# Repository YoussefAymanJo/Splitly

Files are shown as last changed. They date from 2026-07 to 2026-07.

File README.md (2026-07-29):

## Splitly

## Description

corne  hybrid wireless keyboard based .As it consists of a left part keyboard  connected to pc wired ,and right part keyboard powered by a rechargeable Battery which can operate up to week and connected to left part via bluetooth.And operated by nice Nano and CAT display. And a  numpad with RGB colours, connected wired to pc and powered by pico rp2040 .
## Why it was built
I built this,beacause i always need full split mechanical keyboard,but i need to customize it features by myself.So this keyboard it custosmized to my needings.Also,it has customized features based on usage.Splitly is not just regular keybaord but,desgined to be my companion.
## How to use it / Build it
Firsly,printing all 3d models after that fabricate PCB.After that assemble mx switches,MCU and battery management of pcb.then assemble all this parts together.finally,upload firmware on nice nano and pico,the test all 
## Schematic
I made the schematic and keyboard matrix for the corne keyboard, then the  numpad  .

### Left Part



### Right Part



### Numpad



## PCB
I routed the pcb ,then i outlined the shape of 2 keboard parts and numpad .

### Left Part



### Right Part


### Numpad


## CAD
I started   sketching the plate for left & right part keyboard,the i the Enclosure , then the top cover.After that i worked on numpad  plate, then enclosure and top cover,finally i redered them all.

### Left Part





### Right Part






### Numpad






## Firmware
I used kmk with CircuitPython as firmware,and made code for the left  & right part which is keyboard and the numpad

### Left Part






### Right Part





### Numpad


## BOM 
I made the BOM  and needed materials ,in egypt then convert its price to USD dollar.


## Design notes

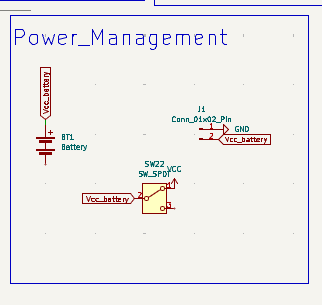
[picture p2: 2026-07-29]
images/Screenshot 2026-07-29 151413.png

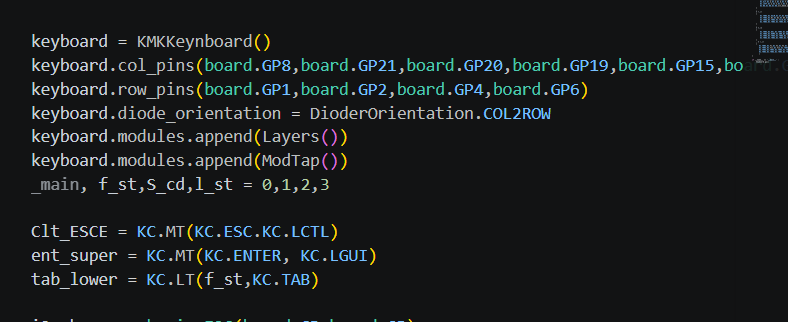
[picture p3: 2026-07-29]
images/Screenshot 2026-07-29 154053.png

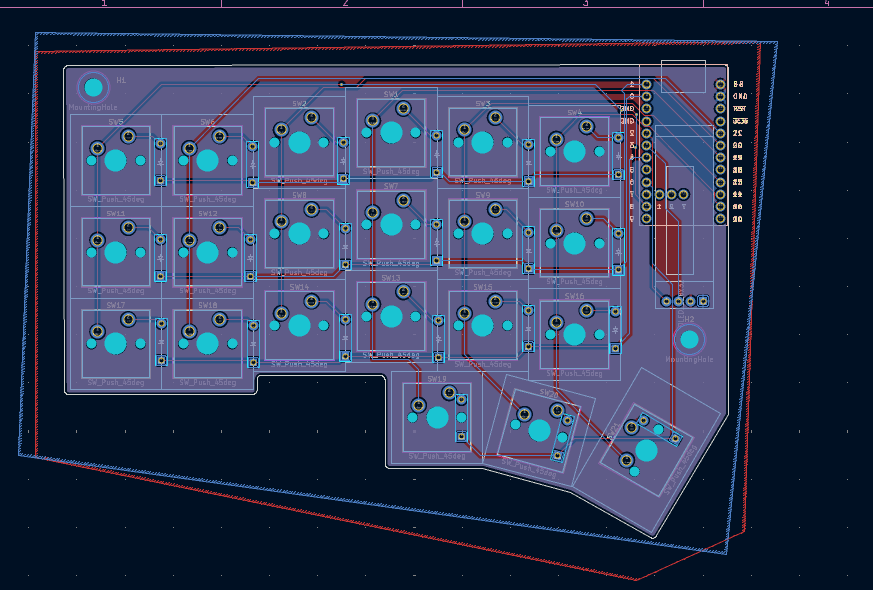
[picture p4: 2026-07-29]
images/Screenshot 2026-07-29 140454.png

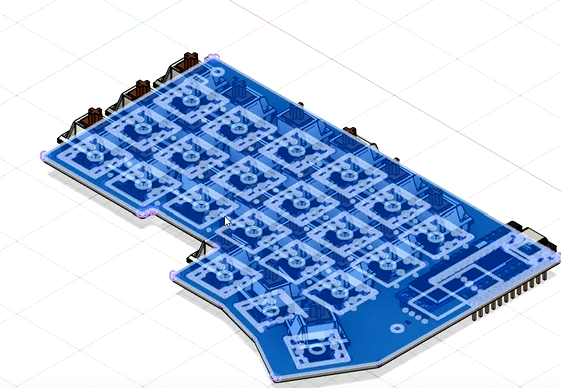
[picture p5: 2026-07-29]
images/Screenshot 2026-07-29 143937.png

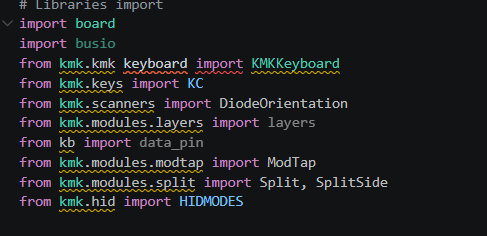
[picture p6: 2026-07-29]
images/Screenshot 2026-07-29 154227.png

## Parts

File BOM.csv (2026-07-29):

Item | descritption | QT | Price | link
Main keyboard_pcb | fabricate and printing it | 3 | 32 | none
3d printing | Printing keyboard parts | 9 | 16 | None
Nice_Nano | Mcu for main keyboard | 2 | 20 | https://www.amazon.com/NRF52840-Development-Bluetooth-Charging-Management/dp/B0DH9FP3JP
Pico | MCU for NUMPAD | 1 | 11.46 | https://microohm-eg.com/raspberry-pi-pico/
Oled Display | Display animation in keyboard | 1 | 3.16 | https://www.ram-e-shop.com/ar/shop/oled-0-96-4pin-oled-0-96-4pin-lcd-display-module-i2c-iic-communicate-7772
Oled display 128*32 | Display animation in keyboard | 1 | 4.27 | https://uge-one.com/product/color-graphic-0-91-i2c-oled-128x32-blue-display-module-ssd1306/
Mx_switches | For keyboard and numpad keys | 108 | 11.19 | https://www.temu.com/ul/kuiper/un9.html?subj=goods-un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
Dsa keycaps | For keyboard and numpad keys | 100 | 19.68 | https://www.aliexpress.us/item/3256808417233251.html?curPageLogUid=AyCtfngZUzYL
M3 shcs 12 mm srews | For connecting enclosures parts together | 20 | 2.31 | https://www.amazon.eg/-/en/Screws-City-12mm-Allen-Socket/dp/B08GY9YFYC?adgrpid=126096347022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
M3 shcs 5 mm screwss | for pcb connection with enclosure | 20 | 1.82 | https://www.temu.com/ul/kuiper/un9.html?subj=goods-un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
Heat insert | Connect srews with enclosure | 20 | 1.92 | https://www.temu.com/ul/kuiper/un9.html?subj=goods-un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
Total | None | None | 123.81

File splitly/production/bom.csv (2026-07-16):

Designator | Footprint | Quantity | Value | LCSC Part #
D1, D10, D11, D12, D13, D14, D15, D16, D17, D18, D19, D2, D20, D21, D3, D4, D5, D6, D7, D8, D9 | Diode_DO-35 | 21 | ~
J1 | OLED_128x32 | 1 | OLED_128x32
SW1, SW10, SW11, SW12, SW13, SW14, SW15, SW16, SW17, SW18, SW19, SW2, SW20, SW3, SW4, SW5, SW6, SW7, SW8, SW9 | MX_PCB_1.00u | 20 | SW_Push_45deg
SW21 | MX_PCB_1.50u | 1 | SW_Push_45deg
U1 | Nice_Nano_V2 | 1 | Nice_Nano_V2

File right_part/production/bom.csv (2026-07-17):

Designator | Footprint | Quantity | Value | LCSC Part #
D1, D10, D11, D12, D13, D14, D15, D16, D17, D18, D19, D2, D20, D21, D3, D4, D5, D6, D7, D8, D9 | Diode_DO-35 | 21 | ~
J1 | JST_PH_S2B-PH-K_1x02_P2.00mm_Horizontal | 1 | Conn_01x02_Pin
SW1 | MX_PCB_1.00u | 1 | I
SW10 | MX_PCB_1.00u | 1 | H
SW11 | MX_PCB_1.00u | 1 | ;
SW12 | MX_PCB_1.00u | 1 | Alt
SW13 | MX_PCB_1.00u | 1 | ,
SW14 | MX_PCB_1.00u | 1 | M
SW15 | MX_PCB_1.00u | 1 | .
SW16 | MX_PCB_1.00u | 1 | N
SW17 | MX_PCB_1.00u | 1 | /
SW18 | MX_PCB_1.00u | 1 | Func
SW19 | MX_PCB_1.00u | 1 | shift
SW2 | MX_PCB_1.00u | 1 | U
SW20 | MX_PCB_1.50u | 1 | bksp
SW21 | MX_PCB_1.00u | 1 | Space
SW22 | SW_Slide_SPDT_Angled_CK_OS102011MA1Q | 1 | SW_SPDT
SW3 | MX_PCB_1.00u | 1 | O
SW4 | MX_PCB_1.00u | 1 | Y
SW5 | MX_PCB_1.00u | 1 | P
SW6 | MX_PCB_1.00u | 1 | Del
SW7 | MX_PCB_1.00u | 1 | K
SW8 | MX_PCB_1.00u | 1 | J
SW9 | MX_PCB_1.00u | 1 | L
U1 | Nice_Nano_V2 | 1 | Nice_Nano_V2

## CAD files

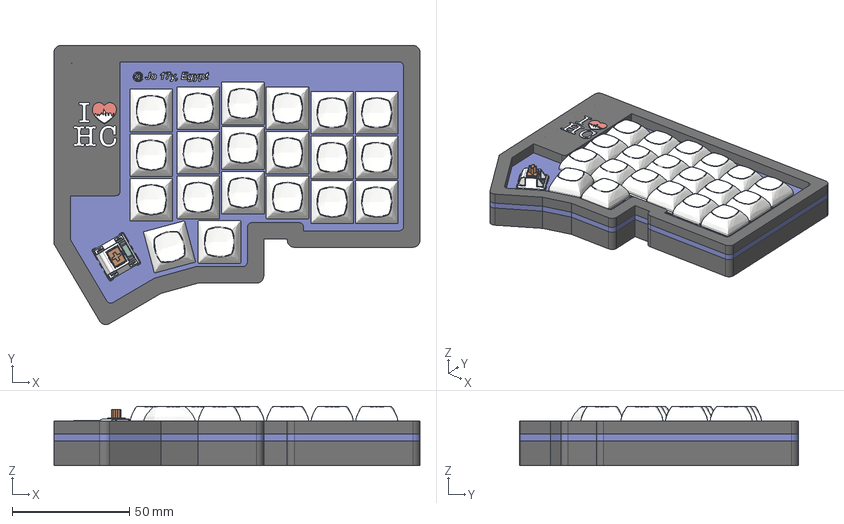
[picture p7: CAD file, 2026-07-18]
Production/Right_Assembly.step
155.9 x 119.0 x 25.3 mm
MX_PCB x 21
JST_PH_S2B-PH-K_1x02_P2.00mm_Horizontal
PinHeader_1x12_P2.54mm_Vertical.step
User Library-TYPE-C-31-M-14.step
MICRO_603 resistor 102
micro_crystal 5x3
MICRO_led
micro_MIC5219
SW_Slide_SPDT_Angled_CK_OS102011MA1Q
Diode_DO-35 x 21
right_part_copper
right_part_via
right_part_silkscreen
right_part_silkscreen_1
right_part_soldermask
right_part_soldermask_1
right_part_PCB

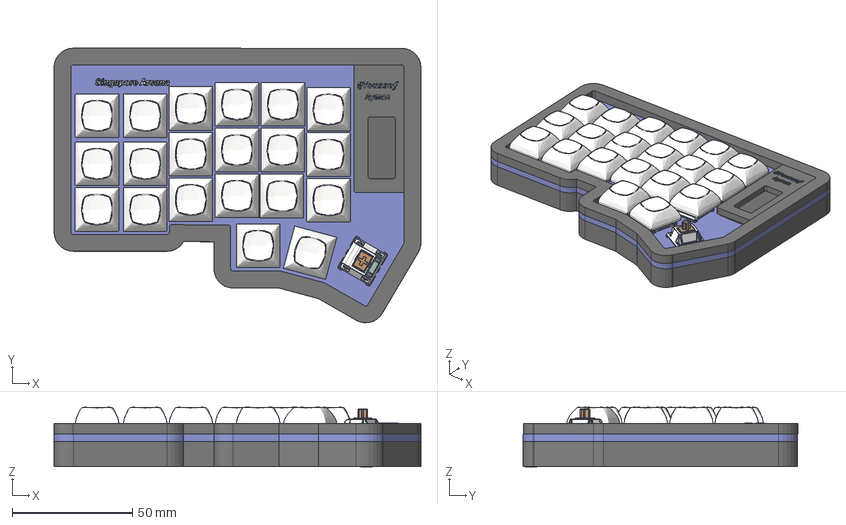
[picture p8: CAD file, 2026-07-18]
Production/Left_Assembly.step
152.7 x 114.3 x 24.8 mm

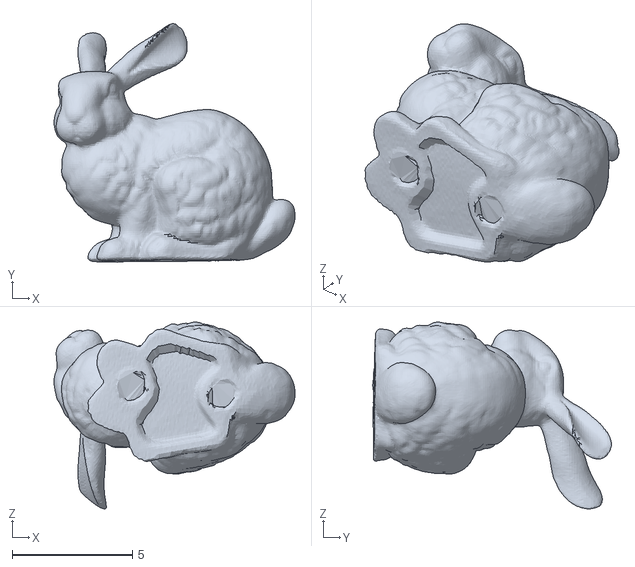
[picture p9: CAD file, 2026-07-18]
Firmware/adafruit-circuitpython-bundle-10.x-mpy-20260606/examples/bno055/bno055_webgl_demo/static/bunny.obj
10.0 x 9.94 x 7.77

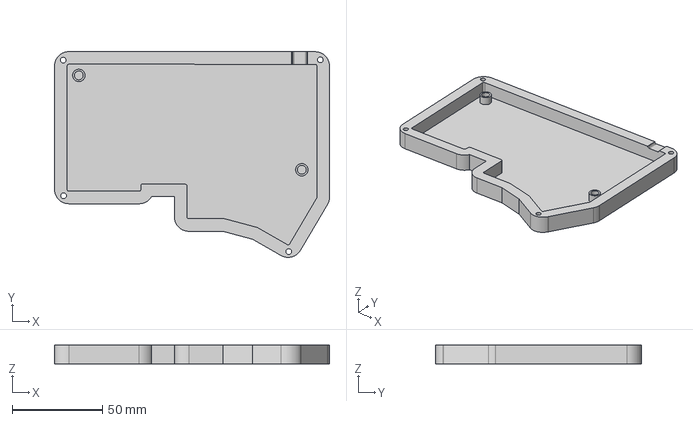
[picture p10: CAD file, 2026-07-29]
Production/Left_ENclosure.step
152.7 x 114.3 x 10.5 mm

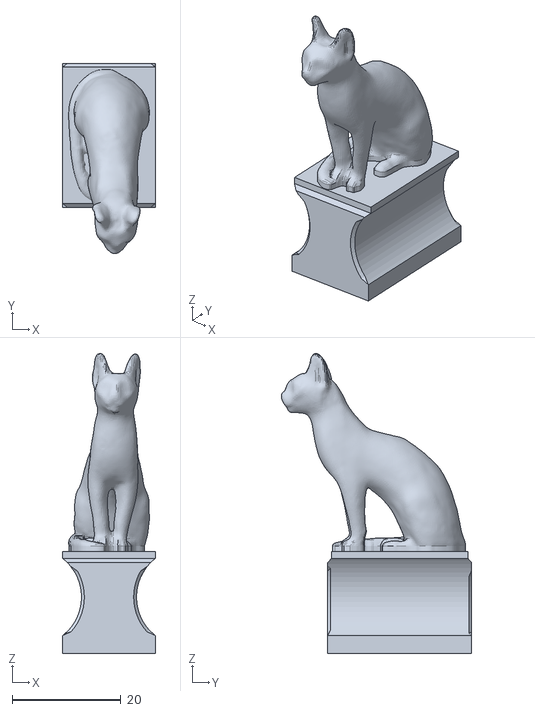
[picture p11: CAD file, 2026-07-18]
Firmware/adafruit-circuitpython-bundle-10.x-mpy-20260606/examples/bno055/bno055_webgl_demo/static/cat_top.stl
17.0 x 34.9 x 55.1

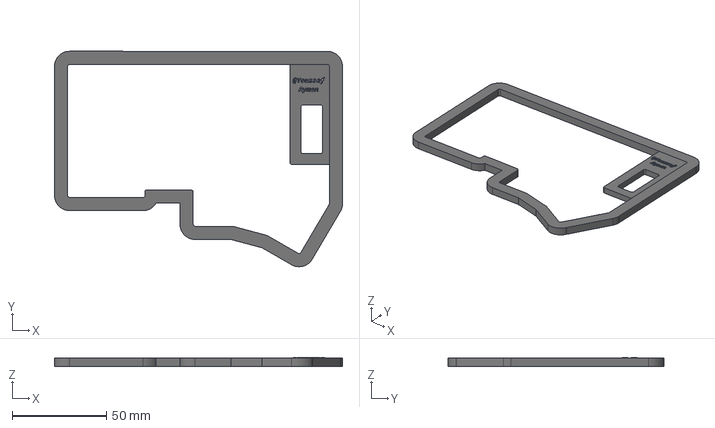
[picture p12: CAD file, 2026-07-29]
Production/left_top_cover.step
152.7 x 114.3 x 4.70 mm

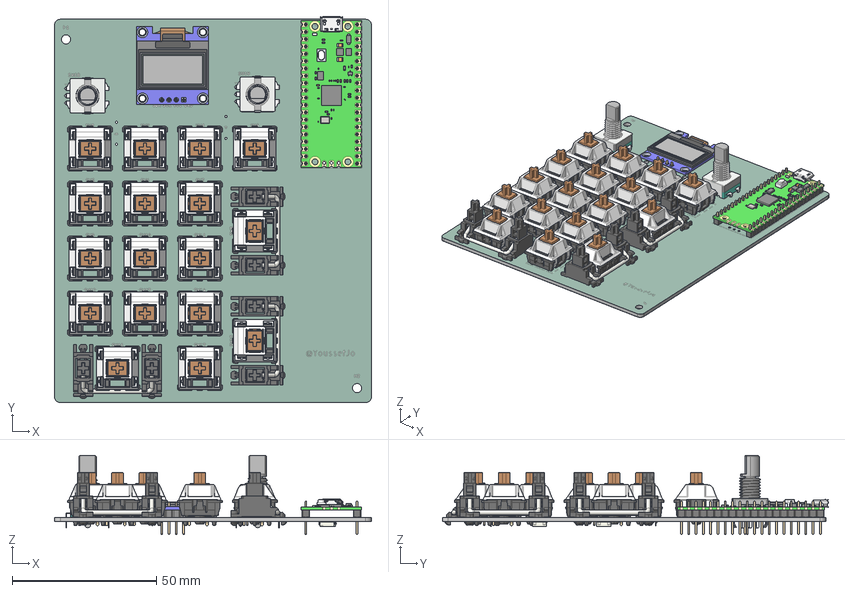
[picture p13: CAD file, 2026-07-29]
Production/pad.step
110.0 x 134.0 x 27.5 mm
MX_PCB x 17
Stabilizer_MX_2.00u x 3
OLED
EC11 x 2
PinHeader_1x20_P2.54mm_Vertical.step
SMD Resistor, Configurable, Raspberry Pi Pico-R3_R7
U2, RT6150B-33GQW, Buck Boost Converter, Raspberry Pi Pico-R3
SMD Capacitor, Configurable, Raspberry Pi Pico-R3_C3
SMD Resistor, Configurable, Raspberry Pi Pico-R3_R14
SMD Capacitor, Configurable, Raspberry Pi Pico-R3_C12
SMD Resistor, Configurable, Raspberry Pi Pico-R3_R2
SMD Capacitor, Configurable, Raspberry Pi Pico-R3_C13
SMD Resistor, Configurable, Raspberry Pi Pico-R3_R12
U3, W25Q16JVUXIQ, Serial NOR Flash 16 Mbit, Raspberry Pi Pico-R3
SMD Resistor, Configurable, Raspberry Pi Pico-R3_R5
SMD Resistor, Configurable, Raspberry Pi Pico-R3_R1
MicroUSB Port, Raspberry Pi Pico-R3
X1, X12M000000S096, 12 Mhz Crystal Resonator, Raspberry Pi Pico-R3
SMD Capacitor, Configurable, Raspberry Pi Pico-R3_C2
SMD Resistor, Configurable, Raspberry Pi Pico-R3_R4
Q1, MOSFET, DMG1012T, Raspberry Pi Pico-R3
SMD Capacitor, Configurable, Raspberry Pi Pico-R3_C11
SMD Resistor, Configurable, Raspberry Pi Pico-R3_R6
RP2040 Microcontroller, Raspberry Pi Pico-R3
SMD Resistor, Configurable, Raspberry Pi Pico-R3_R9
D1, Diode, Schottky, Raspberry Pi Pico-R3
SMD Resistor, Configurable, Raspberry Pi Pico-R3_R3
SMD Capacitor, Configurable, Raspberry Pi Pico-R3_C8
SMD Capacitor, Configurable, Raspberry Pi Pico-R3_C6
SMD Capacitor, Configurable, Raspberry Pi Pico-R3_C17
SMD Capacitor, Configurable, Raspberry Pi Pico-R3_C16
SMD Capacitor, Configurable, Raspberry Pi Pico-R3_C7
SMD Resistor, Configurable, Raspberry Pi Pico-R3_R11
SMD Capacitor, Configurable, Raspberry Pi Pico-R3_C4
D2, QSME-C194, LED, Raspberry Pi Pico-R3
SMD Capacitor, Configurable, Raspberry Pi Pico-R3_C14
SMD Resistor, Configurable, Raspberry Pi Pico-R3_R8
SW1, Tact Switch, Raspberry Pi Pico-R3
SMD Capacitor, Configurable, Raspberry Pi Pico-R3_C9
SMD Resistor, Configurable, Raspberry Pi Pico-R3_R15
SMD Capacitor, Configurable, Raspberry Pi Pico-R3_C5
SMD Resistor, Configurable, Raspberry Pi Pico-R3_R13
SMD Resistor, Configurable, Raspberry Pi Pico-R3_R10
SMD Capacitor, Configurable, Raspberry Pi Pico-R3_C10
L1, Inductor, Raspberry Pi Pico-R3
PCB, Raspberry Pi Pico-R3
SMD Capacitor, Configurable, Raspberry Pi Pico-R3_C1
SMD Capacitor, Configurable, Raspberry Pi Pico-R3_C15
SMD Capacitor, Configurable, Raspberry Pi Pico-R3_C18
LED_WS2812B_PLCC4_5.0x5.0mm_P3.2mm x 2
pad_silkscreen x 2
pad_soldermask x 2
pad_PCB

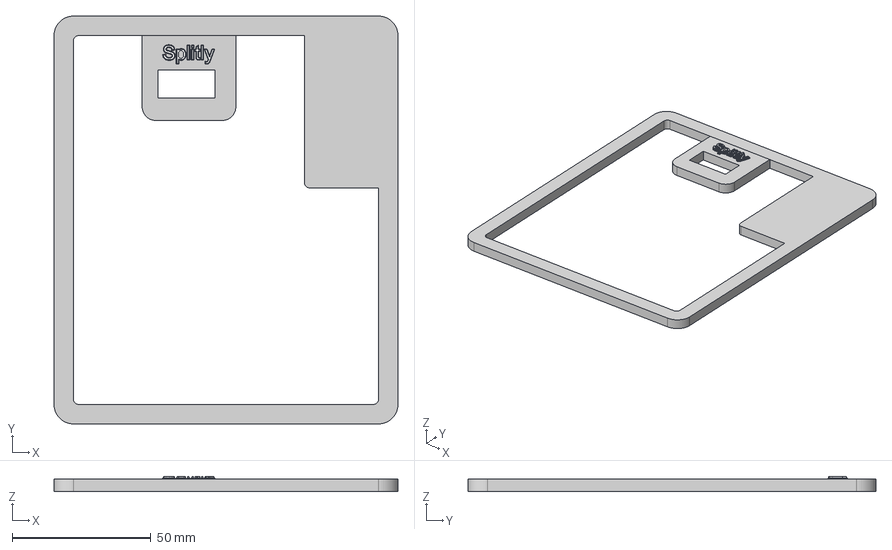
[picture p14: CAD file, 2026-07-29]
Production/Pad_top_cover.step
124.0 x 147.0 x 5.50 mm

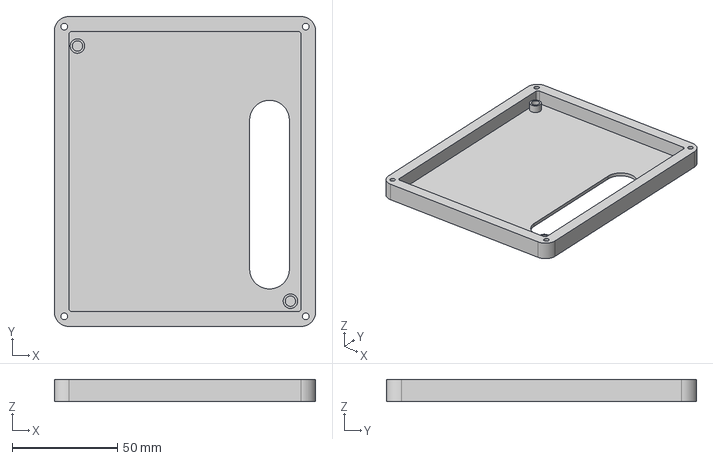
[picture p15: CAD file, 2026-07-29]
Production/Enclosure_pad.step
124.0 x 147.0 x 10.5 mm

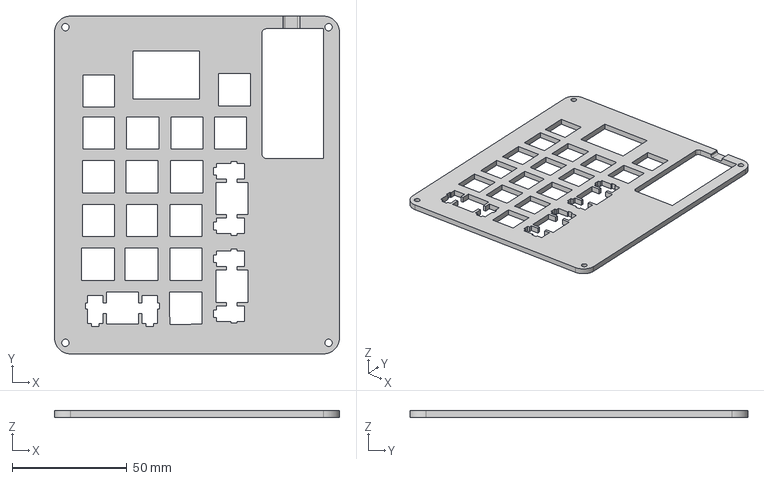
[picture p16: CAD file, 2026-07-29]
Production/Pad+plate.step
124.0 x 147.0 x 3.00 mm

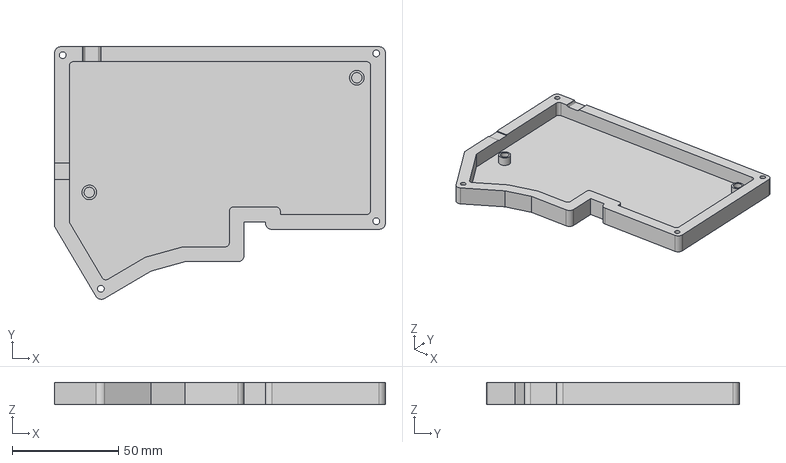
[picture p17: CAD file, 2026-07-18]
Production/Right_Enclosure.step
155.9 x 119.0 x 10.5 mm

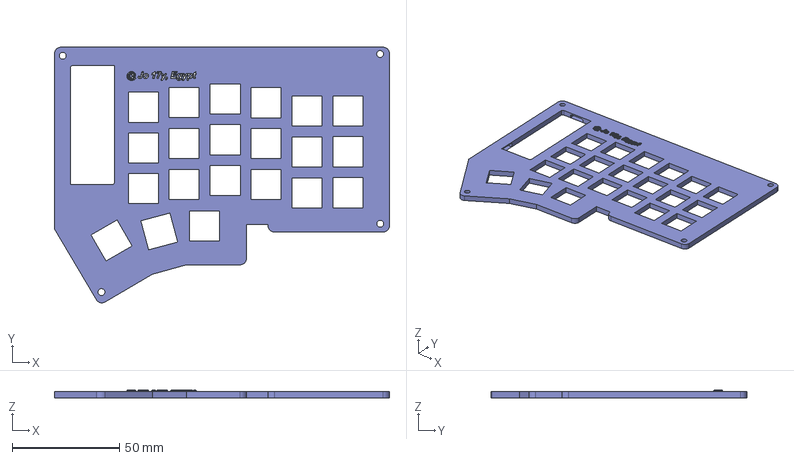
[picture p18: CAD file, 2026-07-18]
Production/Right_plate.step
155.9 x 119.0 x 3.50 mm

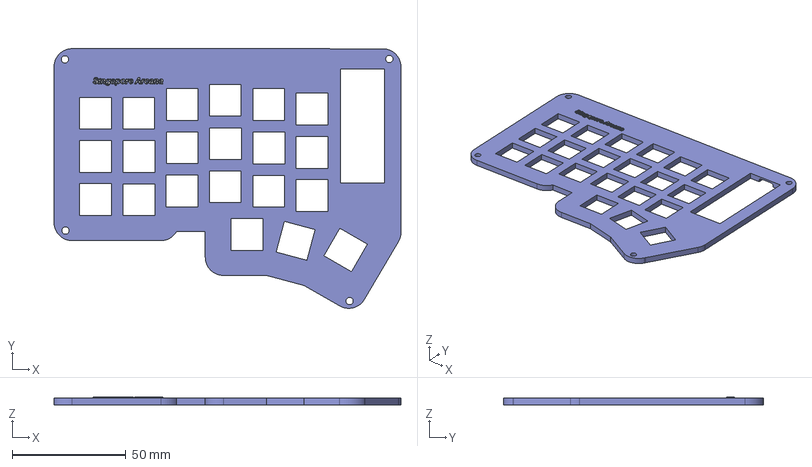
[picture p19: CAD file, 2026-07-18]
Production/Plate.step
152.7 x 114.3 x 3.50 mm

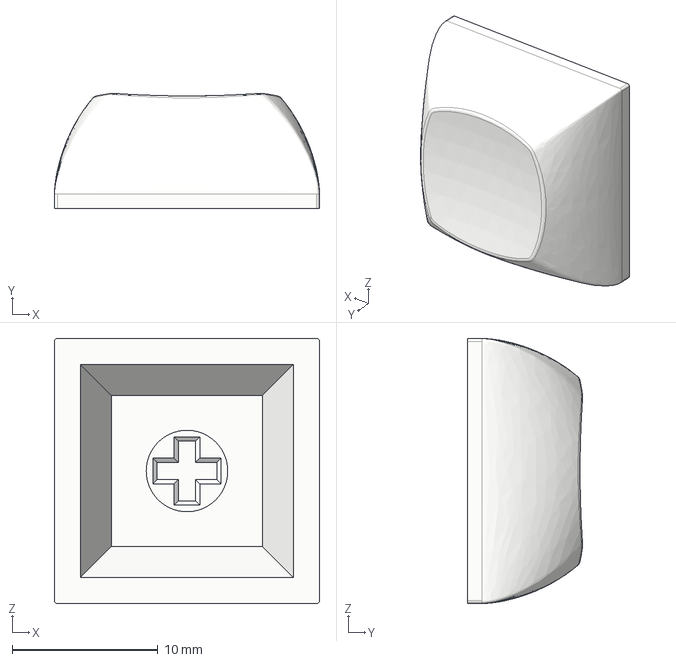
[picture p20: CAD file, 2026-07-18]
Production/DSA_.step
18.2 x 7.91 x 18.2 mm

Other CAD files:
Production/1.5u.step
Production/Right_top_cover.step
Production/M3 Threaded Insert_.step
Production/Battery.step
Production/M3x12 SHCS.step
Production/left_top_cover.f3d
Production/right_part.step
Production/splitly.step
Source_Files/Battery.f3d
Source_Files/Enclosure_pad.f3d
Source_Files/Left_Assembly.f3z
Source_Files/Left_ENclosure.f3d
Source_Files/Pad+plate.f3d
Source_Files/Pad_top_cover.f3d
Source_Files/Plate.f3d
Source_Files/RIght_plae.f3d
Source_Files/Right_Assembly.f3z
Source_Files/Right_Enclosure.f3d
Source_Files/Right_top_cover.f3d
Source_Files/leftPlate.f3d
efc796056b68a6326252bc44c872f28c73b40230_switch.dxf

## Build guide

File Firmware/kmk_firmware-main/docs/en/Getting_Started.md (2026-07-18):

# Getting Started
> Life was like a box of chocolates. You never know what you're gonna get.

KMK is a keyboard focused layer that sits on top of [CircuitPython](https://circuitpython.org/). As such, it should work with most [boards that support CircuitPython](https://circuitpython.org/downloads). KMK requires CircuitPython version 7.3 or above.
Known working and recommended devices can be found in the [list of officially supported microcontrollers](Officially_Supported_Microcontrollers.md)

## TL;DR Quick start guide
> To infinity and beyond!
1. [Install CircuitPython version 7.3 or higher on your board](https://learn.adafruit.com/welcome-to-circuitpython/installing-circuitpython). With most boards, it should be as easy as drag and dropping the firmware on the drive
2. Get an up to date [copy of KMK](https://github.com/KMKfw/kmk_firmware/archive/refs/heads/main.zip) from the main branch 
3. Unzip it and copy the KMK folder and the boot.py file at the root of the USB drive corresponding to your board (often appearing as CIRCUITPY)
4. Create a new *code.py* or *main.py* file in the same root directory (same level as boot.py) with the example content hereunder: 

***IMPORTANT:*** adapt the GP0 / GP1 pins to your specific board !

```
print("Starting")

import board

from kmk.kmk_keyboard import KMKKeyboard
from kmk.keys import KC
from kmk.scanners import DiodeOrientation

keyboard = KMKKeyboard()

keyboard.col_pins = (board.GP0,)
keyboard.row_pins = (board.GP1,)
keyboard.diode_orientation = DiodeOrientation.COL2ROW

keyboard.keymap = [
    [KC.A,]
]

if __name__ == '__main__':
    keyboard.go()
```

5. With a wire / paperclip / whatever, connect the pins you selected for col_pin and row_pin together.

feather and keeboar example pins


6. If it prints the letter "a" (or a "Q" or ... depending on your keyboard layout), you're done!

## Now that you're up and running, you may want to go further...
> This is your last chance. After this, there is no turning back. You take the blue pill—the story ends, you wake up in your bed and believe whatever you want to believe. You take the red pill—you stay in Wonderland, and I show you how deep the rabbit hole goes. Remember: all I'm offering is the truth. Nothing more.

### You're extremely lucky and you have a fully supported keyboard
If your keyboard and microcontroller are officially supported, simply visit the page for your files, and dropping them on the root of the "flash drive".
Those pages can be found in the repositories [boards folder](https://github.com/KMKfw/kmk_firmware/tree/master/boards).
You will need the `kb.py` and `main.py`. If you need more detailed instructions on how to customize the configuration settings and key mappings, please refer to the [config and keymap](config_and_keymap.md) documentation.

### You've got another, maybe DIY, board and want to customize KMK for it  
First, be sure to understand how your device work, and particularly its specific matrix configuration. You can have a look at [how key matrices work](http://pcbheaven.com/wikipages/How_Key_Matrices_Works/) or read the [guide](https://docs.qmk.fm/#/hand_wire) provided by the QMK team for handwired keyboards
Once you've got the gist of it:
- To start customizing your `code.py`/`main.py` file, please refer to the [config and keymap](config_and_keymap.md) and [keys](keys.md) files respectively, which provide detailed instructions on how to modify the configuration settings and key mappings.
- There's a [reference](keycodes.md) of the available keycodes
- [International](international.md) extension adds keys for non US layouts and [Media Keys](media_keys.md) adds keys for ... media

And to go even further:
- [Macros](macros.md) are used for sending multiple keystrokes in a single action
- [Layers](layers.md) can transform the whole way your keyboard is behaving with a single touch
- [HoldTap](holdtap.md) allow you to customize the way a key behaves whether it is tapped or hold, and [TapDance](tapdance.md) depending on the number of times it is pressed

Want to have fun features such as RGB, split keyboards and more? Check out what builtin [modules](modules.md) and [extensions](extensions.md) can do!
You can also get ideas from the various [user examples](https://github.com/KMKfw/kmk_firmware/tree/master/user_keymaps) that we provide and dig into our [documentation](README.md).

### Pre-compiling KMK for faster boot times or microcontrollers with limited flash

There are two options:
1. To compile KMK yourself you'll need to download and install the [compatible mpy-cross](https://adafruit-circuit-python.s3.amazonaws.com/index.html?prefix=bin/mpy-cross/)
  for your Operating System. Don't forget to add it to your PATH, test by running `mpy-cross` from a shell (Powershell, Bash, Fish, etc). Once that's set up, run either `make compile` (if you have `make`) or `python util/compile.py`to generate the `.mpy` versions of KMK files. Then copy the whole compiled `kmk/` directory to your keyboard.

There are even more compile and copy make targets.
Power user can compile KMK and additional libraries, and then load the bytecode and keyboard code
onto a keyboard in one go:
```sh
make compile copy-compiled copy-board MPY_SOURCES='kmk/ lib/' BOARD='boards/someboard' MOUNTPOINT='/media/user/someboard'
```

2. To download a pre-compiled KMK go to [Actions > Build on the KMK GitHub project page](https://github.com/KMKfw/kmk_firmware/actions/workflows/compile.yml),
  click on the latest build, and you'll find the download link at the bottom of the page under Artifacts. Unzip the download and place the contents in the `kmk/` directory on your keyboard.

On certain microcontrollers that will still not be enough of a size reduction to
fit all of KMK onto the flash (nice!nano for example).
You can remove any optional parts of KMK you aren't using.
Start by skipping `kmk/extensions`, `kmk/modules`, and `kmk/quickpin` and adding in only the files under those paths used in your keyboard (i.e. files that are imported in your `main.py` or `kb.py`).

## Additional help and support
> Roads? Where we're going we don't need roads.

In case you need it, debugging help can be found on the [debugging](debugging.md) page.

For asynchronous support and chatter about KMK, [join our Zulip
community](https://kmkfw.zulipchat.com)!

If you ask for help in chat or open a bug report, if possible
make sure your copy of KMK is up-to-date.
In particular, swing by the Zulip chat *before* opening a GitHub Issue about
configuration, documentation, etc. concerns.

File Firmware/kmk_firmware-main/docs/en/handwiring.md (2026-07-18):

# Handwire keyboards
This guide will not talk about the physical wiring. Check out our 
[recommended microcontrollers](Officially_Supported_Microcontrollers.md) and 
follow this amazing [hand wiring guide](https://docs.qmk.fm/#/hand_wire). That 
guide can be followed until you are setting up the firmware. After wiring the 
keyboard, you can refer to our [porting guide](porting_to_kmk.md)

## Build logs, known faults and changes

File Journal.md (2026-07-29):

author: Youssef Ayman Mohamed

description: corne hybrid wireless keyboard based .As it consists of a left part keyboard connected to pc wired ,and right part keyboard powered by a rechargeable Battery which can operate up to week and connected to left part via bluetooth.And operated by nice Nano and CAT display. And a numpad with RGB colours, connected wired to pc and powered by pico rp2040 .

created_at: "2026-07-15"

## Entry 1 
created at:2026-7-15

### Content 
During this session, I  mainly worked on searching for and sketching out the workflow and materials.Firstly,i searched about split keyboard types and found corne keyboard layout achieve my requirments ,from size and distrubution of keys,after that,i watched videos and searched about corne keyboard keycomponets.and most 
of them use Nice Nano as Mcu and it does not require power chargers as it has it own.

After that, i use draw.io to sketch keyboard worflow.i starting adding MCU ,after watching  video about wireless keyboard connection and MCu.then i started adding switches,which wil be cherry mx and dsa keycaps,and searched on reddit about corne layout.then i added display chossing oled 128*32.

I decided left part,will be wired connection because display,and right part will connect to wireless.then i starting seacrhing for sutiable battery for rigth part.
Finally,i searched for numpad and mcu i will use (pico rp 2040) ,then i added it to workflow and will be connected to pc wired ,beacuse of oled 128*64 and rgb light in numpad.



### Recording (44 min) :
https://lapse.hackclub.com/timelapse/c5cdFFcw_wo8

## Entry 2
created at:2026-7-15

### Content 
During this session ,i worked mainly of left part schematic & PCB.firstly,First, I added and organized a switch from Scottkeebs' library based on my keyboard layout. Then I started connecting the switches in rows and columns , forming a keyboard matrix.
After that,i add nice nano ,i started connecting columns & rows of matrix to it.and added rectangles to each part such as matrix and nicnano,adding some organizing in schematic.then i added oled screen ,and connect it to nice nano.then assigned footprint for each componets.


After that,i worked on pcb,i uploaded left part json file,and upload it to keyboard library on kicad to organize layout.but it lack ,as switched names were missing.then i cotinued adding 3d model for oled and nice nano.
After that,while i routing i found sw order was wrong switches coming another in same row.then i started edit on their name to be accurate order.And started routing sws and align diodes with their switches.then i started routing matrix and oled to nice nano.

After , that i added mounting holes for m3 screws,to set pcb on enclosure.after that,i reroute pcb edge cuts lines.
Finally,i added filled zones on top for Vcc and lower for GND.


### Recording (2 hour & 2 min) :

https://lapse.hackclub.com/timelapse/jyOiTPzKX9hP

## Entry 3
created at:2026-7-16

### Content 
During this session ,i worked mainly of left part 3d models and assembly.firstly,i uploaded pcb 3d model to fusion,then started project pcb outline , switches ,MCU and oled.after that, i uploaded projected dxf and worked on plate.Firslty,i routed plate outline leaving space between pcb and plate sketch.after that, i offest it and adding filleset on edges.after that,i checked plate aligment with pcb using section analaysis.
Then,i started adding switches opening based on sketch.then check switches aligment with openig and hanged on its edges.after that,i extruded plate by 3mm,and added moutning holes at edges to,where m3 screws will attached to enclosure.finally,cutting rectangle area in plate for nice nano and display oled.



Secondly,i worked on main enclosure.firtly, i extruded it based on plate sketch dxf file,then extrude the bottom layer by 2 mmm, then i checked it height with pcb using section analysis,and adjust its height.after that, i cut 5.5 circle from the bottom mounting holes,where m3 head will be in ,with heigth 3mm.
After that,i checked heatinsert dimesnions ,and aligment of enlcosure and pcb heigth in it.then extrude circle with diamter of heatinsert.in which srews will be in it and hold pcb at specific heigth, preventing PCB pins attach bottom layer.


After that,i assembled all togehter and check aligment.then i started adding keycapd for switches,after that i started adding srews and heat insert and checking aligment by section analsis form top and rigth.then,i sketched nice nano usb opening ,then cut it from plate and enclosure.
After that,i worked on top cover,extrude it with same plate dxf file.and adding covering rectangle for nicnano.then i started cut form the back mounting holes for heatinsert that connected srews of enclosure.then,i assembled all together ,and adding enclosure srews and heatinsert.
then,sign my name on top cover and exlode text,also signed arcana name on plate.


Finally,i worked on render it,trying different colours,and choosed black ,white and gold.



### Recording (3 hour & 55 min) :

https://lapse.hackclub.com/timelapse/jyOiTPzKX9hP

## Entry 4
created at:2026-7-17

### Content 

During this session ,i worked mainly of right part schematic & PCB.firstly,i sketched process diamgram of keyboard connection,and the type of connection to each part.


then, I added and organized a switch from Scottkeebs' library based on my keyboard layout. Then I started connecting the switches in rows and columns , forming a keyboard matrix.After that,i add nice nano ,i started connecting columns & rows of matrix to it.and added rectangles to each part such as matrix and nicnano,adding some organizing in schematic.then i searched of slide sw name on kicad,then starting adding power managemnet,adding switches,and jst pin header that connected to battery,then route jst with switch and nicenano.then assigned footprint for each component.



After that,i worked on pcb,i uploaded rigth part json file,and upload it to keyboard library on kicad to organize layout.then i cotinued adding 3d model for nice nano.After that,while i routing i found sw order was wrong switches coming another in same row.then i started edit on their name to be accurate order.After , tt i added mounting holes for m3 screws,to set the PCB on enclosure then, i route pcb edge cuts lines. and adding fillset ant corners,And started routing sws and align diodes with their switches.then i started routing matrix  to nice nano.then,i adjust jst pin header location,to be engouh space for battery. After , tt iha added mounting holes for m3 screws,to set the PCB on enclosure.After that, i route pcb edge cuts lines.
Finally,i added filled zones on top for Vcc and lower for GND.



### Recording (2 hour & 16 min) :

https://lapse.hackclub.com/timelapse/1gOH3Y6zuYtc
https://lapse.hackclub.com/timelapse/MOm_24O0OcwB

## Entry 5
created at:2026-7-18

### Content 
During this session ,i worked mainly of right part 3d models and assembly.firstly,i searched for suitable battery and found one,the i extrude its dimesnions for assemly,and sign it power on it.then,i uploaded pcb 3d model to fusion,then started project pcb outline , switches ,MCU and .after that, i uploaded projected dxf and worked on plate.Firslty,i routed plate outline leaving space between pcb and plate sketch.after that, i offest it and adding filleset on edges.after that,i checked plate aligment with pcb using section analaysis. Then,i started adding switches opening based on sketch.then check switches aligment with openig and hanged on its edges.after that,i extruded plate by 3mm,and added moutning holes at edges to,where m3 screws will attached to enclosure.finally,cutting rectangle area in plate for nice nano a.




Secondly,i worked on main enclosure.firtly, i extruded it based on plate sketch dxf file,then extrude the bottom layer by 2 mmm, then i checked it height with pcb using section analysis,and adjust its height.after that, i cut 5.5 circle from the bottom mounting holes,where m3 head will be in ,with heigth 3mm.
After that,i checked heatinsert dimesnions ,and aligment of enlcosure and pcb heigth in it.then extrude circle with diamter of heatinsert.in which srews will be in it and hold pcb at specific heigth, preventing PCB pins attach bottom layer.


After that,i sketched nice nano usb opening ,then cut it from plate and enclosure,then i assembled all togehter and check aligment.then i started adding keycaps for switches,after that i started adding srews and heat insert and checking aligment by section analsis form top and rigth.then adding enclosure srews and heatinsert.
After that,i worked on top cover,extrude it with same plate dxf file.and adding covering rectangle for nicnano.then i started cut form the back mounting holes for heatinsert that connected srews of the enclosure.then,i assembled all together ,then i assembled battery in space part between jst and nicnano and try to adjust it location.then i assembled it ,then adjust ot top cover againg to cover all the battery and pico without intersect.

then,i  searched for hackclub stickers ,and dowload one,the convert it to svg.after that ,i uploaded it to top cover,then extrude it by 0.5mm.after that,i rendered it with same colours in the image.then i signed my name on plate and explode text and offest charcters,then extrude it by 0.5 and offset by 2.5mm ,then i renders them with white and blue.


Finally,i rendered full right assembly , with black ,white and blue.


after that,i edit of left part,rewrite singapore arcana pharse ,and offest characters,then exturde them,and also signed my name on top cover and extrude it .then i redered text with white and red ,and the keyboard with same appeareance of right part.


### Recording (4 hour & 29 min) :

https://lapse.hackclub.com/timelapse/TiGkd2mVcwAl

## Entry 6
created at:2026-7-18

### Content 
During this session,  I worked manily on main keyboard firmware,i used kmk python version,and i will add more update on code during buidling and test project.
Firstly, I created the main file for the left part. then starting intializing and importing libraries, and import library for displa, HID, and kmk keyboard libraries.


Then, I started defining the keyboard  matrix GPIO pins in the MCU.then making layers and modtap to customize more functions in the same switch.
Then, I defined my keymap, by 4 layers, the first one for alphabetical and the other  layers for other full keyboard switches such as Fn switches.




Secondly,i iniatize display screen ,then define it pins,after that , i make it show my name on the top and cat image,then i set it properties from heigth ,brigthness and increase brigtness by 0.2 for 500 ms.
After that, I initialize ae wireless HID connection,where the right part will be connected to it.


In the second file(right.py) for the right part, then starting intializing and importing libraries, and import library for HID and kmk keyboard libraries.



Then, I started define keyboard  matrix GPIO pins inthe  MCU.then making layers and modtap to customize more functions in same switch.
Then, I defined my keymap, with 4 layers, first one for alphabetical and the  other  layers for other full keyboard switches such as Fn switches.


Finally, i initalize in it with a wireless connection and define it displaying name.


### Time (1 hour & 36 min) :

## Entry 7
created at:2026-7-29

### Content 
During this session,i worked mainly on numpad schematic & PCB, firstly,i started adding switches and order them into matrix based on numpad layout.then,i added diodes and route columns and rows together.then i added pico symbol from scotto library, then i added 2 ec11 switch rotary encoder,and connect their switch pins  to matrix on  row 1
after that,i added row and columns flags.

Then, i added oled 128*64 and added it pins flags,then i added 2 rgb ws8b128 leds and define their pins flags.finally,i routed all flags in pico.And add organizing rectangles to each part such as pico pinout.then,i assign footprint to components, and adding mouting holes for m3 screws.

Secondly,i update pcb , and upload json file to keyboard library to organize switches.but it found issues in organize encoders in matrix,so i did it manually.Then, i found some switches order were wrong, so i redit their names.then,i started routing keyboard matrix.then, i added encoders ,oled and pico 3d models.
After that, i continued routing another parts,and flibbed rgb leds to back layer.,then adding filling zone on top layer for vcc and on on lower for GND.finally,i worked on solvind appeared DRC errors ,then sign my name on PCB,then export pcb step file and gerbers.



### Recording (1 hour & 25 min) :

https://lapse.hackclub.com/timelapse/xZpGC4tF1jRX

## Entry 8
created at:2026-7-29

### Content 
During this session,i worked on numpad enlosure and redereing.Firstly,i edited on PCB edges,adding polish it and adding fillset at corners.then update step file.
After that,i uploaded plate for pcb and edit on it dimensions.increase plat width and length to cover all pcb,then i offset it by 7mm , leaving enough space for moutning holes.then i checked plate switches opening on PCB,and found  after using surface anaylsis,switch openig not alig well with switches.then,i resketch switches opeing and , started adjusting their dimensions and shifting them to left by 1 mm .then increase encoders and oled opening.After that , i made mountinig holes for m3 screws that will connect enclosure.
then, i mirrored them vertically and horizontally.then i opened rectangle for pico ,avoid intersect  pico with plate.


After that,I worked on Main enclosure.i extrude outline first based on plate dxf outline,then extrude bottom of enclosure by 2 mm.After that,i cut circle of 5.5mm for bottom mouting with height 3 mm ,in which m3 screws head will be in.then i assembled plate,pcb and enclosure together checking aligment,and measure the needed height for pcb holder.then i extrude 2 circle wit diameter 4.9mm, where heatinsert be in connecting srews and hold pcb ,at specific height.
After that, i used section analysis to project pico usb openig.then i upload dxf on enclosure and cut it .But,i found its not alig with usb so i moved to by 1.5mm to the left.then i cut the same opeing in plate,then opened slot form back for rgb light.


After that,i worked on top_Cover,firstly, uploaded dxf of plate layout,then extrude only offset and pico covering rectangle.then,i cutted form the back mouting openig for heatinserts that connects enclosure screws.after that,i extrude covering part for oled part.then i cut rectanel for the middle based on oled display screen.After that,i signed "spilty" project name on top cover,and explode it ,then offset letters by 0.25mm.then extrude them by 0.5 and outer part by 0.25.after that i redered word splitly by white  & red .


Finally,I worked on finishing assembly,adding m3 screws & heatinserts for enclosure and PCB and align them using section analysis.After that,i added keycaps and encoder caps with hackclub letter.finaly,i rendered it with same keyboard colour platte.


### Recording (2 hour & 38 min) :

https://lapse.hackclub.com/timelapse/aSH0zesMmBYj
https://lapse.hackclub.com/timelapse/BIEeWwLMjhyU

## Entry 9
created at:2026-7-29

### Content 
during this session,i worked mainly,on numpad code and  BOM file.  i used kmk python version,and i will add more update on code during buidling and test project.I created the pad file for the  numpad part. then starting intializing and importing rgb libraries, and kmk keyboard libraries..Then, I started defining the keyboard  matrix GPIO pins in the MCU.Then, I defined my keymap, by 1 layers.
then i defined encoders pins and define their function as control volume and cotrast.



then, i worked on BOM,firstly,i edit on pad schematic,as  row 3 was connected to gnd,so i changed it,then udpate gerbers.
After that,i started uplaod pcb gerbers files and add their price on BOM,the upload 3d models.Then i searched for MCU and oled in EGypt.then Mx switches and keycaps i found them on alipay ant temue.finally,i searched for screws and heatinsert.


### Time (20 min ) code 

### Recording (20 min ) :
https://lapse.hackclub.com/timelapse/dg1qAvqC9TMs

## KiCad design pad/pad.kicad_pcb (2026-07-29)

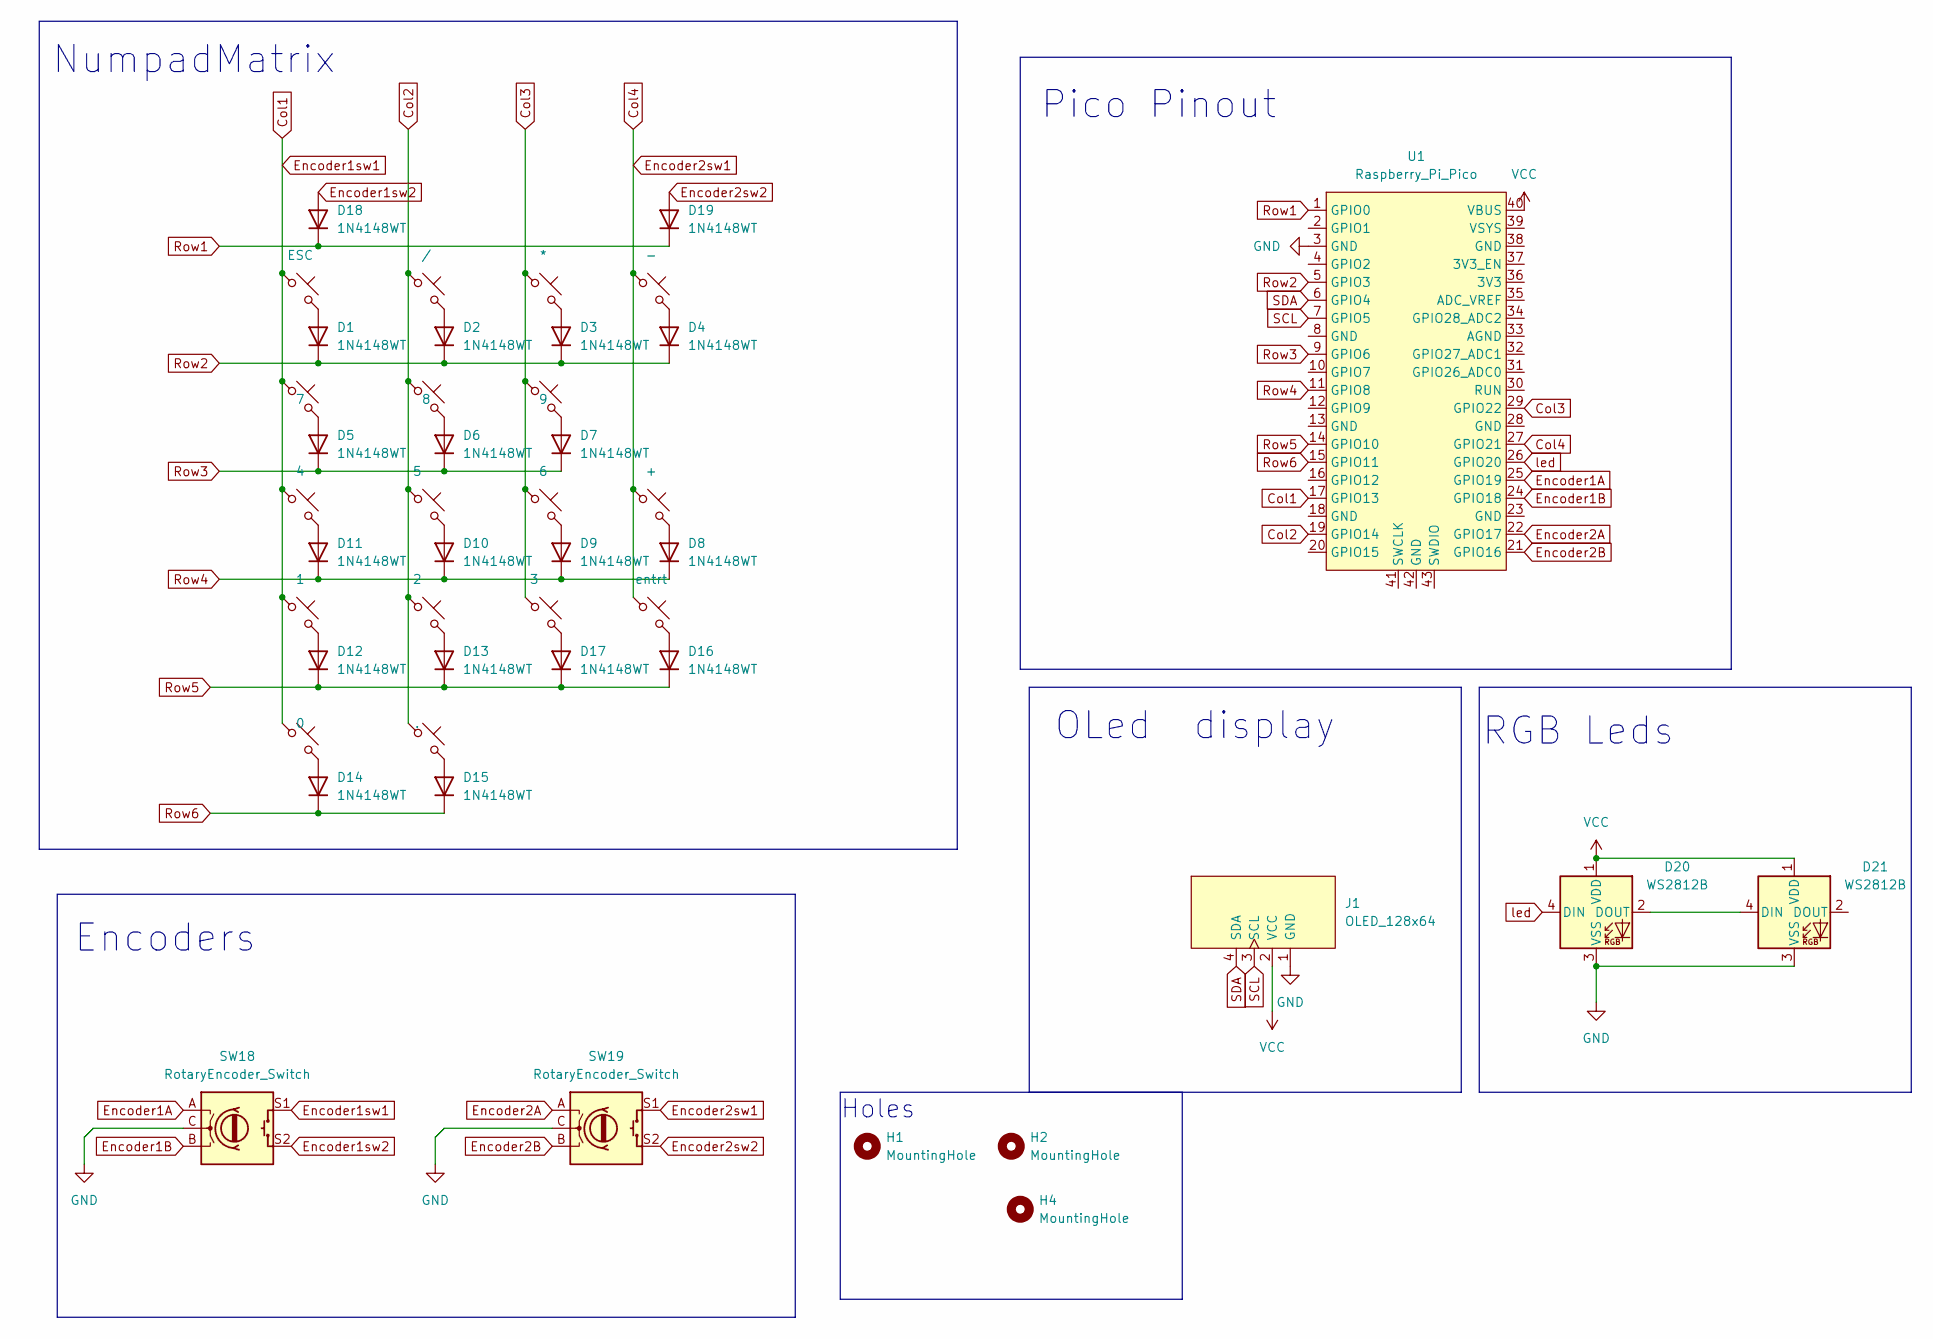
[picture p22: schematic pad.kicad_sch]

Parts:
D1, D2, D3, D4, D5, D6, D7, D8, D9, D10, D11, D12, D13, D14, D15, D16, D17, D18, D19: 1N4148WT; Diode_DO-35
D20, D21: WS2812B; LED_WS2812B_PLCC4_5.0x5.0mm_P3.2mm
H1, H2, H4: MountingHole; MountingHole_3.2mm_M3
J1: OLED_128x64
SW1: ESC; MX_PCB_1.00u
SW2: /; MX_PCB_1.00u
SW3: *; MX_PCB_1.00u
SW4: -; MX_PCB_1.00u
SW5: 7; MX_PCB_1.00u
SW6: 8; MX_PCB_1.00u
SW7: 9; MX_PCB_1.00u
SW8: +; MX_PCB_2.00u
SW9: 4; MX_PCB_1.00u
SW10: 5; MX_PCB_1.00u
SW11: 6; MX_PCB_1.00u
SW12: 1; MX_PCB_1.00u
SW13: 2; MX_PCB_1.00u
SW14: 3; MX_PCB_1.00u
SW15: entrt; MX_PCB_2.00u
SW16: 0; MX_PCB_2.00u
SW17: .; MX_PCB_1.00u
SW18, SW19: RotaryEncoder_Switch; RotaryEncoder_Alps_EC11E-Switch_Vertical_H20mm_MountingHoles
U1: Raspberry_Pi_Pico

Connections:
Col1: SW1.1, SW5.1, SW9.1, SW12.1, SW16.1, SW18.S1, U1.17 (GPIO13)
Col2: SW2.1, SW6.1, SW10.1, SW13.1, SW17.1, U1.19 (GPIO14)
Col3: SW3.1, SW7.1, SW11.1, SW14.1, U1.29 (GPIO22)
Col4: SW4.1, SW8.1, SW15.1, SW19.S1, U1.27 (GPIO21)
Encoder1A: SW18.A, U1.25 (GPIO19)
Encoder1B: SW18.B, U1.24 (GPIO18)
Encoder1sw2: D18.2 (A), SW18.S2
Encoder2A: SW19.A, U1.22 (GPIO17)
Encoder2B: SW19.B, U1.21 (GPIO16)
Encoder2sw2: D19.2 (A), SW19.S2
GND: D20.3 (VSS), D21.3 (VSS), J1.1 (GND), SW18.C, SW19.C, U1.3 (GND)
unnamed: D1.2 (A), SW1.2
unnamed: D2.2 (A), SW2.2
unnamed: D3.2 (A), SW3.2
unnamed: D4.2 (A), SW4.2
unnamed: D5.2 (A), SW5.2
unnamed: D6.2 (A), SW6.2
unnamed: D7.2 (A), SW7.2
unnamed: D8.2 (A), SW8.2
unnamed: D9.2 (A), SW11.2
unnamed: D10.2 (A), SW10.2
unnamed: D11.2 (A), SW9.2
unnamed: D12.2 (A), SW12.2
unnamed: D13.2 (A), SW13.2
unnamed: D14.2 (A), SW16.2
unnamed: D15.2 (A), SW17.2
unnamed: D16.2 (A), SW15.2
unnamed: D17.2 (A), SW14.2
unnamed: D20.2 (DOUT), D21.4 (DIN)
Row1: D18.1 (K), D19.1 (K), U1.1 (GPIO0)
Row2: D1.1 (K), D2.1 (K), D3.1 (K), D4.1 (K), U1.5 (GPIO3)
Row3: D5.1 (K), D6.1 (K), D7.1 (K), U1.9 (GPIO6)
Row4: D8.1 (K), D9.1 (K), D10.1 (K), D11.1 (K), U1.11 (GPIO8)
Row5: D12.1 (K), D13.1 (K), D16.1 (K), D17.1 (K), U1.14 (GPIO10)
Row6: D14.1 (K), D15.1 (K), U1.15 (GPIO11)
SCL: J1.3 (SCL), U1.7 (GPIO5)
SDA: J1.4 (SDA), U1.6 (GPIO4)
VCC: D20.1 (VDD), D21.1 (VDD), J1.2 (VCC), U1.40 (VBUS)
led: D20.4 (DIN), U1.26 (GPIO20)

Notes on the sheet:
Encoders
Pico Pinout
RGB Leds
Holes
OLed display
NumpadMatrix

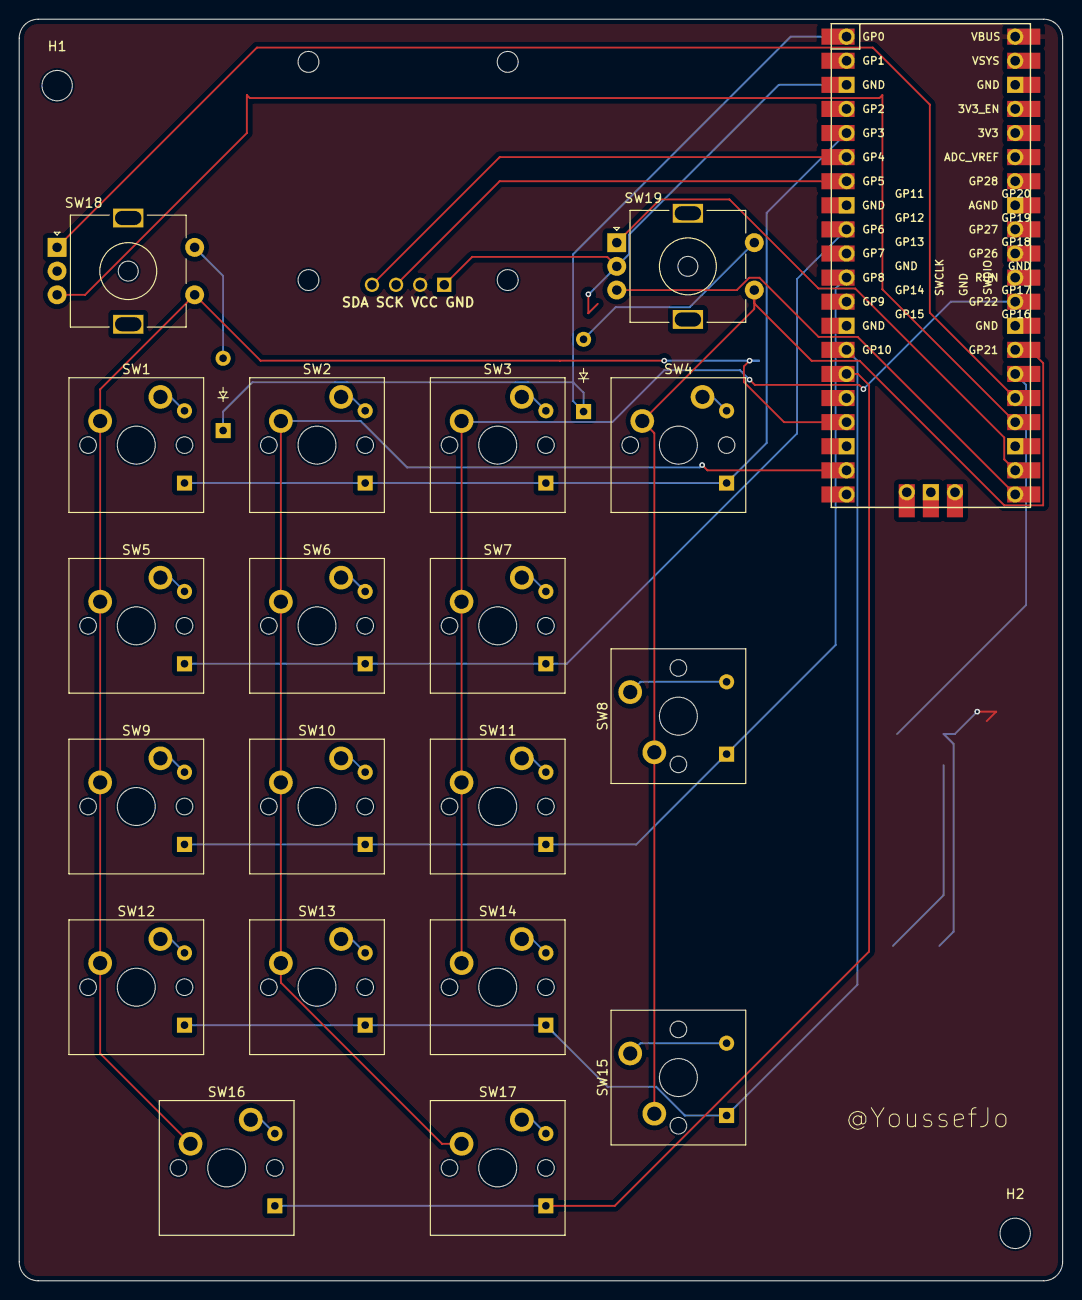
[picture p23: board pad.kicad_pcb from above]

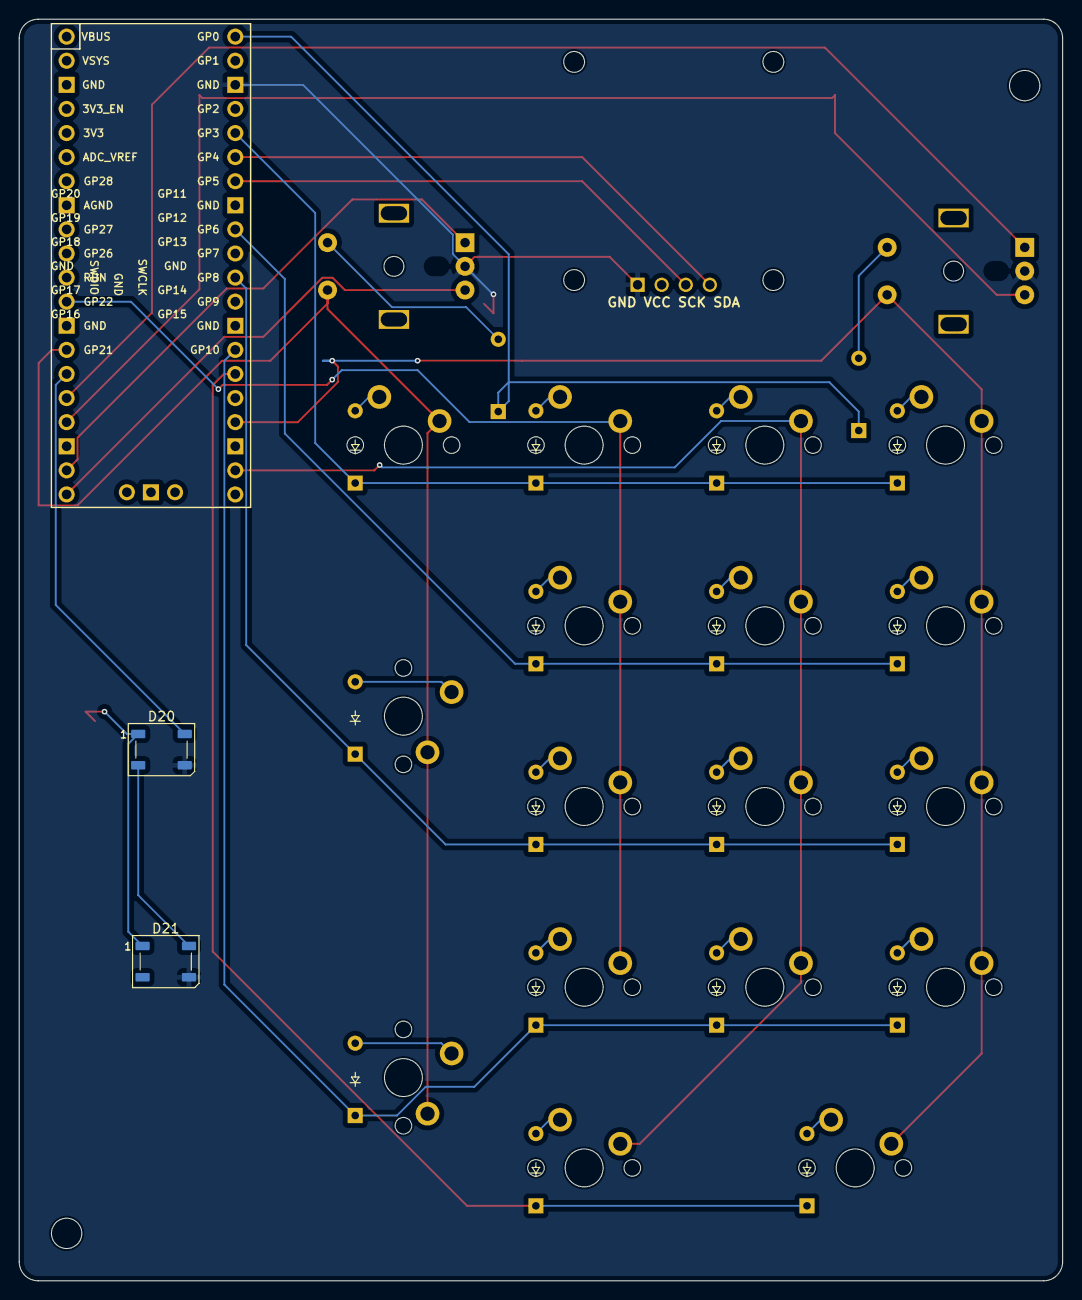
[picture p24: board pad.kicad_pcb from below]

Board: 2 copper layers, 110.0 x 133.0 mm, 45 parts (19 on the bottom side), 39 nets.

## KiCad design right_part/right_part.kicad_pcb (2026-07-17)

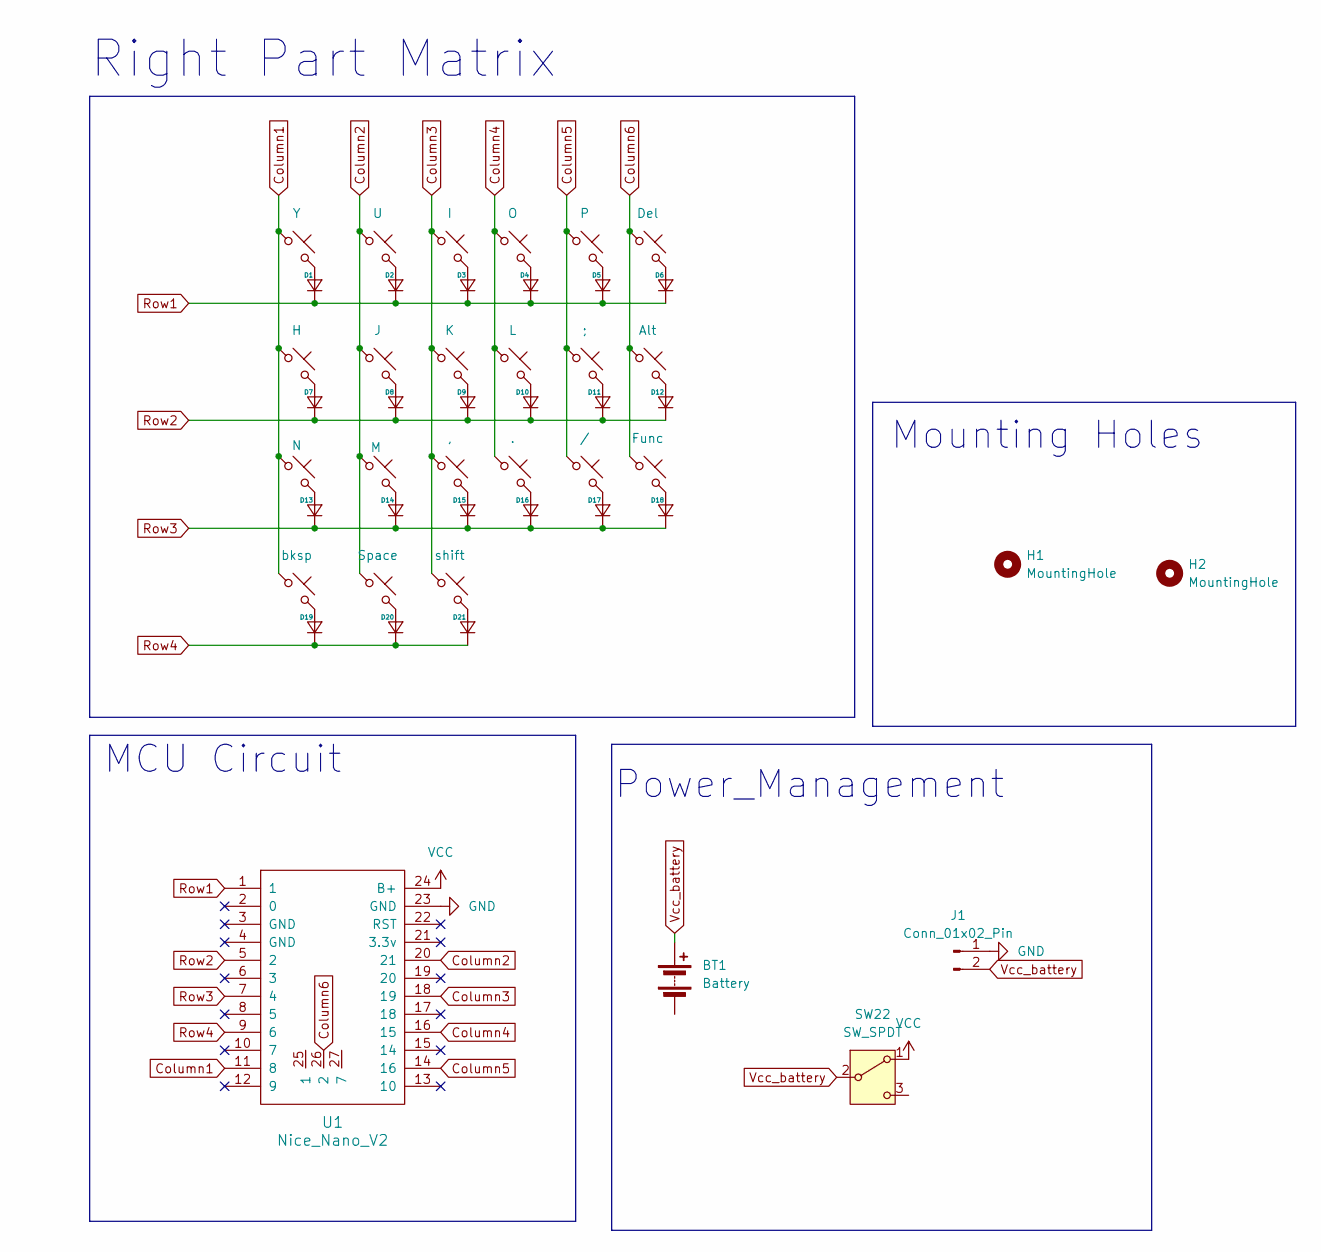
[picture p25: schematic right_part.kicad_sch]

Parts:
BT1: Battery
D1, D2, D3, D4, D5, D6, D7, D8, D9, D10, D11, D12, D13, D14, D15, D16, D17, D18, D19, D20, D21: Diode_DO-35
H1, H2: MountingHole; MountingHole_3.2mm_M3
J1: Conn_01x02_Pin; JST_PH_S2B-PH-K_1x02_P2.00mm_Horizontal
SW1: I; MX_PCB_1.00u
SW2: U; MX_PCB_1.00u
SW3: O; MX_PCB_1.00u
SW4: Y; MX_PCB_1.00u
SW5: P; MX_PCB_1.00u
SW6: Del; MX_PCB_1.00u
SW7: K; MX_PCB_1.00u
SW8: J; MX_PCB_1.00u
SW9: L; MX_PCB_1.00u
SW10: H; MX_PCB_1.00u
SW11: ;; MX_PCB_1.00u
SW12: Alt; MX_PCB_1.00u
SW13: ,; MX_PCB_1.00u
SW14: M; MX_PCB_1.00u
SW15: .; MX_PCB_1.00u
SW16: N; MX_PCB_1.00u
SW17: /; MX_PCB_1.00u
SW18: Func; MX_PCB_1.00u
SW19: shift; MX_PCB_1.00u
SW20: bksp; MX_PCB_1.50u
SW21: Space; MX_PCB_1.00u
SW22: SW_SPDT; SW_Slide_SPDT_Angled_CK_OS102011MA1Q
U1: Nice_Nano_V2

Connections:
Column1: SW4.1, SW10.1, SW16.1, SW20.1, U1.11 (8)
Column2: SW2.1, SW8.1, SW14.1, SW21.1, U1.20 (21)
Column3: SW1.1, SW7.1, SW13.1, SW19.1, U1.18 (19)
Column4: SW3.1, SW9.1, SW15.1, U1.16 (15)
Column5: SW5.1, SW11.1, SW17.1, U1.14 (16)
Column6: SW6.1, SW12.1, SW18.1, U1.26 (2)
GND: J1.1, U1.23 (GND)
unnamed: D1.2 (A), SW4.2
unnamed: D2.2 (A), SW2.2
unnamed: D3.2 (A), SW1.2
unnamed: D4.2 (A), SW3.2
unnamed: D5.2 (A), SW5.2
unnamed: D6.2 (A), SW6.2
unnamed: D7.2 (A), SW10.2
unnamed: D8.2 (A), SW8.2
unnamed: D9.2 (A), SW7.2
unnamed: D10.2 (A), SW9.2
unnamed: D11.2 (A), SW11.2
unnamed: D12.2 (A), SW12.2
unnamed: D13.2 (A), SW16.2
unnamed: D14.2 (A), SW14.2
unnamed: D15.2 (A), SW13.2
unnamed: D16.2 (A), SW15.2
unnamed: D17.2 (A), SW17.2
unnamed: D18.2 (A), SW18.2
unnamed: D19.2 (A), SW20.2
unnamed: D20.2 (A), SW21.2
unnamed: D21.2 (A), SW19.2
Row1: D1.1 (K), D2.1 (K), D3.1 (K), D4.1 (K), D5.1 (K), D6.1 (K), U1.1
Row2: D7.1 (K), D8.1 (K), D9.1 (K), D10.1 (K), D11.1 (K), D12.1 (K), U1.5 (2)
Row3: D13.1 (K), D14.1 (K), D15.1 (K), D16.1 (K), D17.1 (K), D18.1 (K), U1.7 (4)
Row4: D19.1 (K), D20.1 (K), D21.1 (K), U1.9 (6)
VCC: SW22.1 (A), U1.24 (B+)
Vcc_battery: BT1.1 (+), J1.2, SW22.2 (B)

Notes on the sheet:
Mounting Holes
MCU Circuit
Power_Management
Right Part Matrix

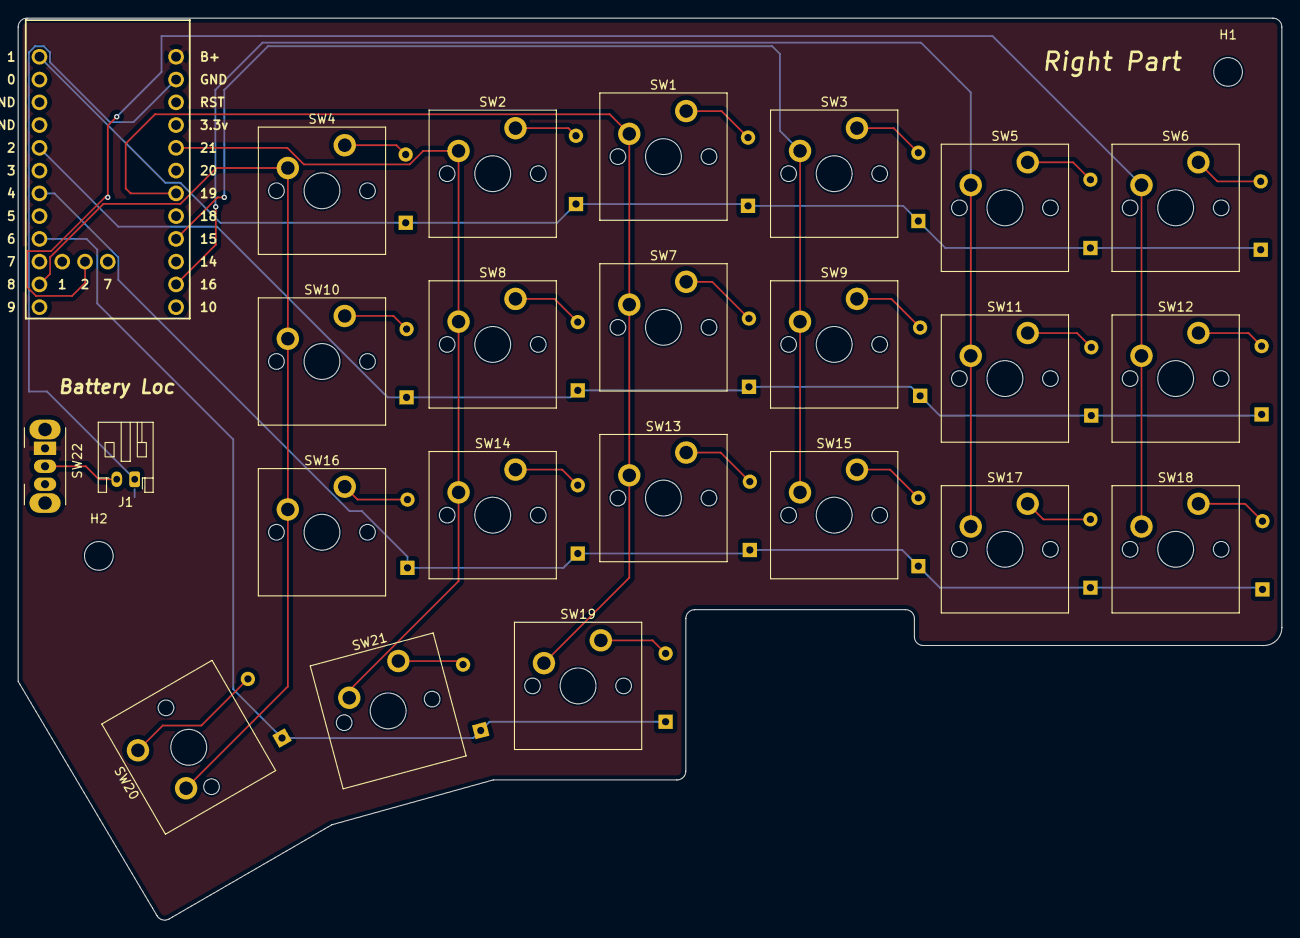
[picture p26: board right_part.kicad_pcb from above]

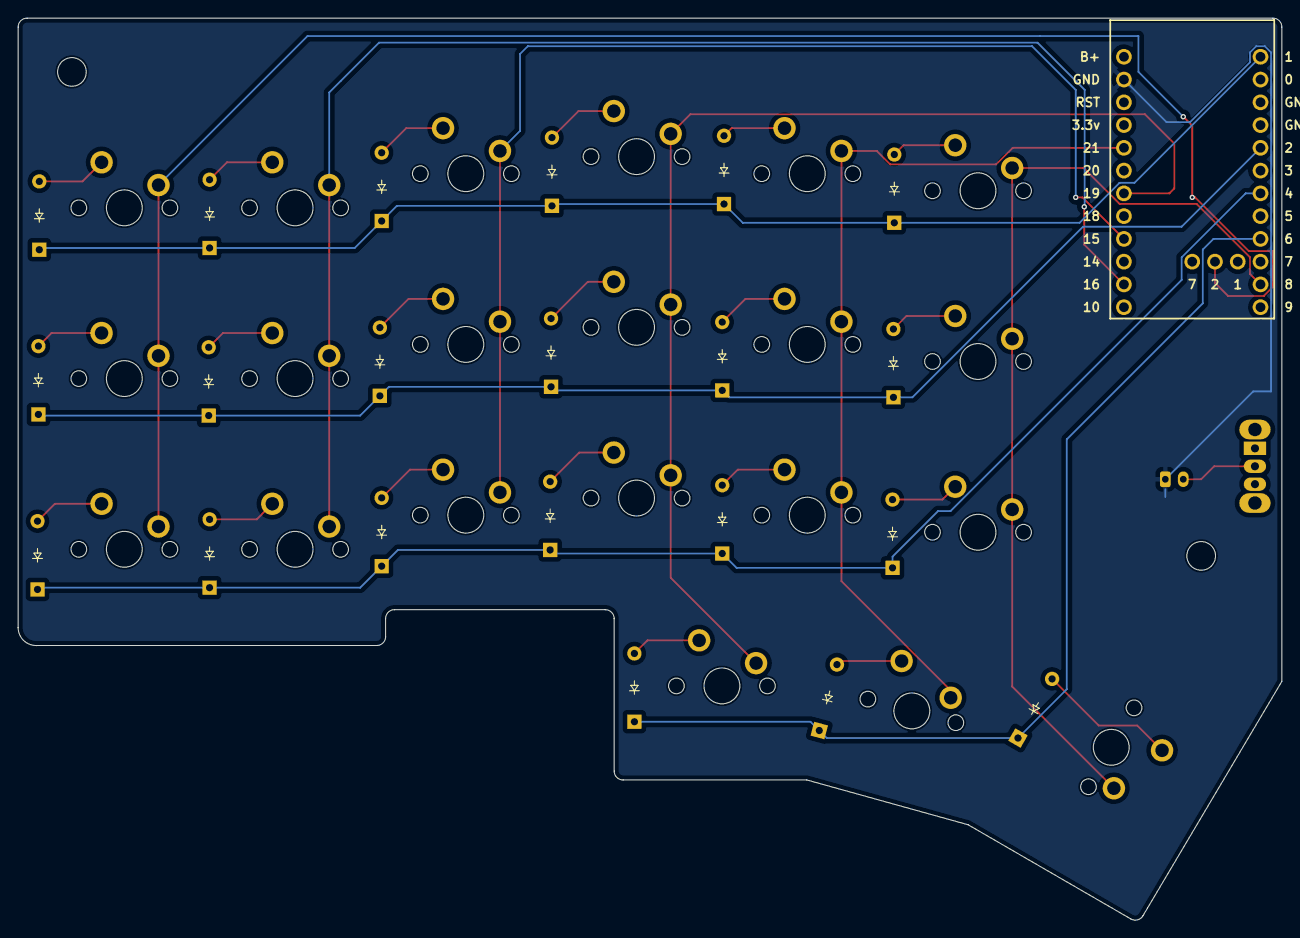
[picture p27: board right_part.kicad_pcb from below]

Board: 2 copper layers, 141.0 x 100.6 mm, 47 parts (21 on the bottom side), 34 nets.

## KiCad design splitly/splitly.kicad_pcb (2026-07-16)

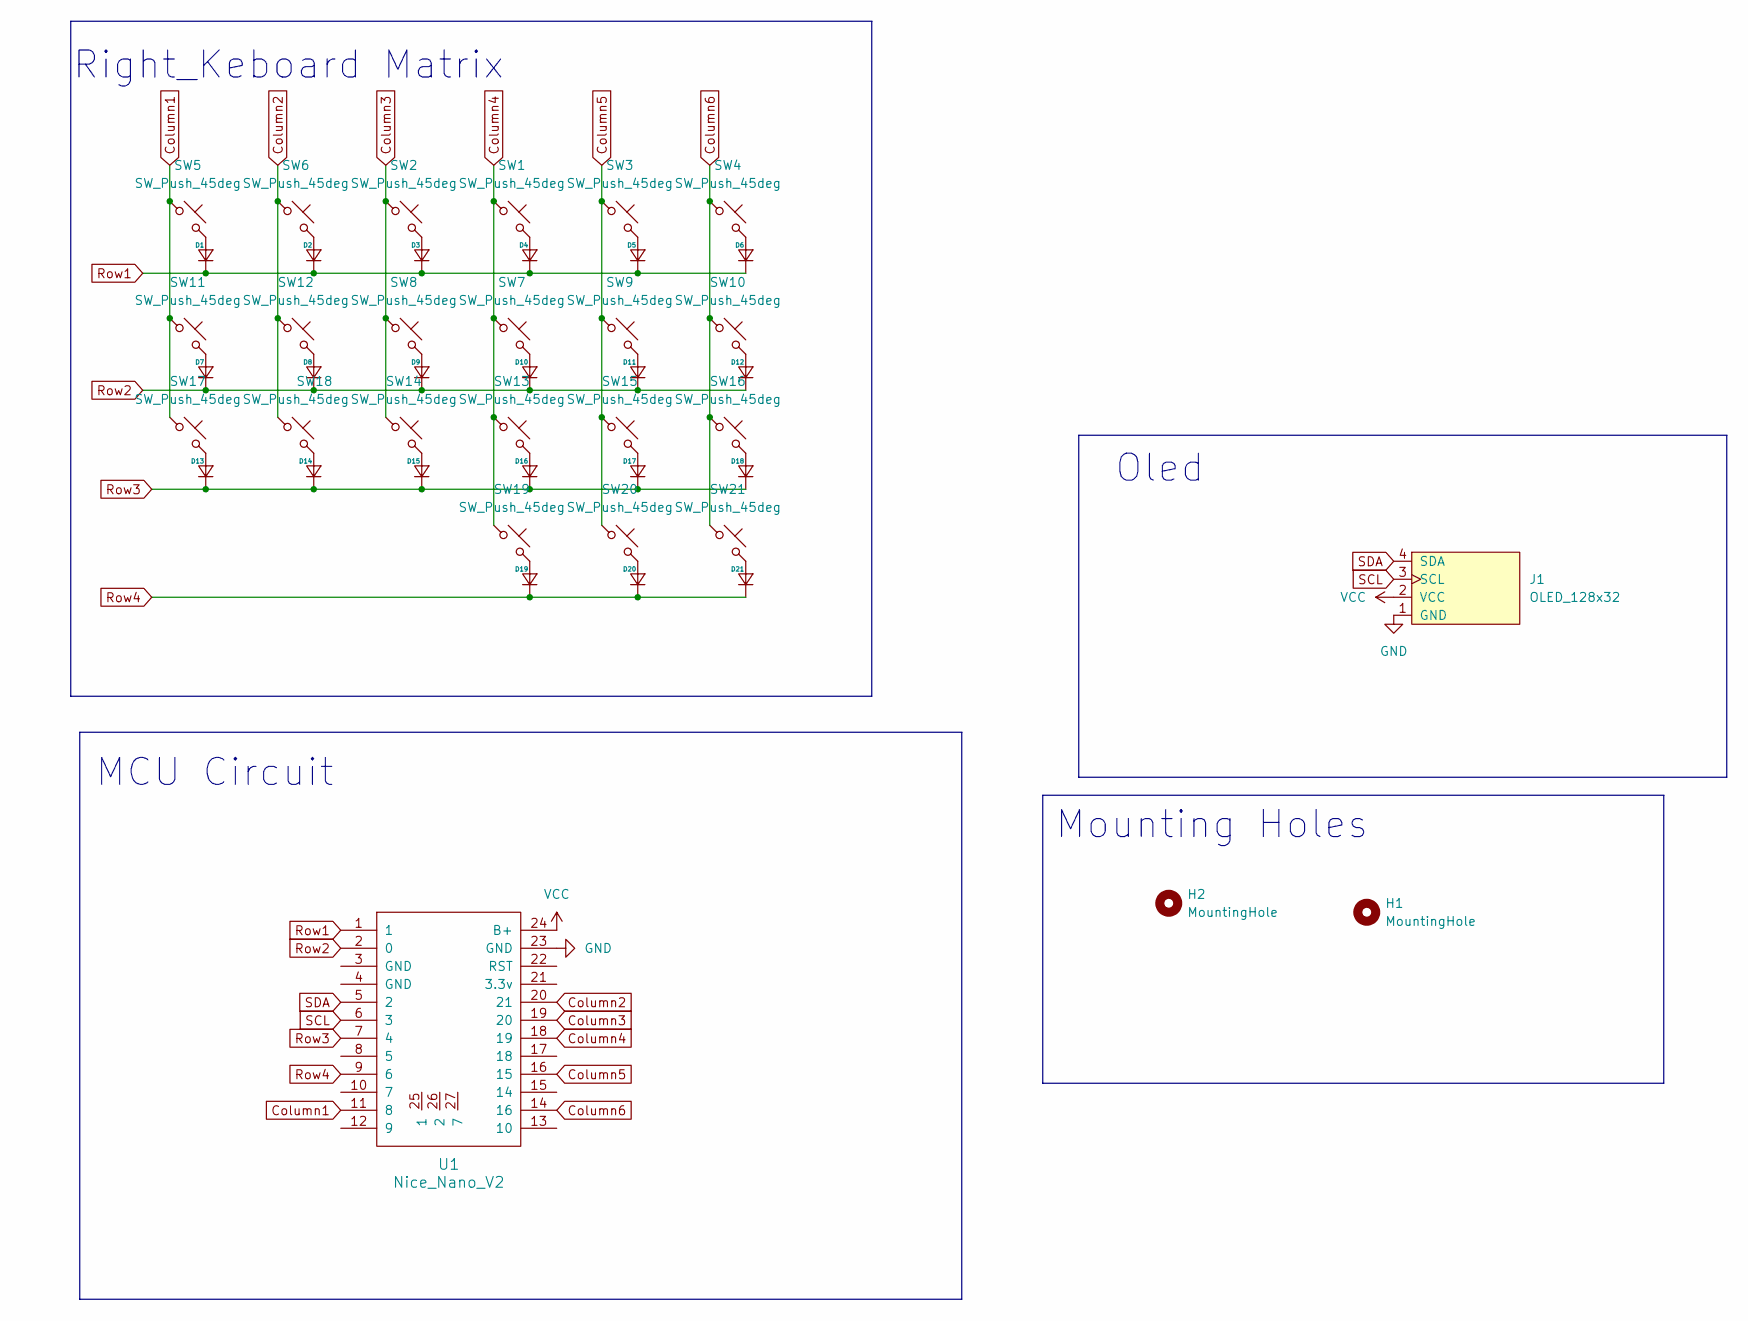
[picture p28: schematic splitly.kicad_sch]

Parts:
D1, D2, D3, D4, D5, D6, D7, D8, D9, D10, D11, D12, D13, D14, D15, D16, D17, D18, D19, D20, D21: Diode_DO-35
H1, H2: MountingHole; MountingHole_3.2mm_M3
J1: OLED_128x32
SW1, SW2, SW3, SW4, SW5, SW6, SW7, SW8, SW9, SW10, SW11, SW12, SW13, SW14, SW15, SW16, SW17, SW18, SW19, SW20: SW_Push_45deg; MX_PCB_1.00u
SW21: SW_Push_45deg; MX_PCB_1.50u
U1: Nice_Nano_V2

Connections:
Column1: SW5.1, SW11.1, SW17.1, U1.11 (8)
Column2: SW6.1, SW12.1, SW18.1, U1.20 (21)
Column3: SW2.1, SW8.1, SW14.1, U1.19 (20)
Column4: SW1.1, SW7.1, SW13.1, SW19.1, U1.18 (19)
Column5: SW3.1, SW9.1, SW15.1, SW20.1, U1.16 (15)
Column6: SW4.1, SW10.1, SW16.1, SW21.1, U1.14 (16)
GND: J1.1 (GND), U1.23 (GND)
unnamed: D1.2 (A), SW5.2
unnamed: D2.2 (A), SW6.2
unnamed: D3.2 (A), SW2.2
unnamed: D4.2 (A), SW1.2
unnamed: D5.2 (A), SW3.2
unnamed: D6.2 (A), SW4.2
unnamed: D7.2 (A), SW11.2
unnamed: D8.2 (A), SW12.2
unnamed: D9.2 (A), SW8.2
unnamed: D10.2 (A), SW7.2
unnamed: D11.2 (A), SW9.2
unnamed: D12.2 (A), SW10.2
unnamed: D13.2 (A), SW17.2
unnamed: D14.2 (A), SW18.2
unnamed: D15.2 (A), SW14.2
unnamed: D16.2 (A), SW13.2
unnamed: D17.2 (A), SW15.2
unnamed: D18.2 (A), SW16.2
unnamed: D19.2 (A), SW19.2
unnamed: D20.2 (A), SW20.2
unnamed: D21.2 (A), SW21.2
Row1: D1.1 (K), D2.1 (K), D3.1 (K), D4.1 (K), D5.1 (K), D6.1 (K), U1.1
Row2: D7.1 (K), D8.1 (K), D9.1 (K), D10.1 (K), D11.1 (K), D12.1 (K), U1.2 (0)
Row3: D13.1 (K), D14.1 (K), D15.1 (K), D16.1 (K), D17.1 (K), D18.1 (K), U1.7 (4)
Row4: D19.1 (K), D20.1 (K), D21.1 (K), U1.9 (6)
SCL: J1.3 (SCL), U1.6 (3)
SDA: J1.4 (SDA), U1.5 (2)
VCC: J1.2 (VCC), U1.24 (B+)

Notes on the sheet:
Right_Keboard Matrix
MCU Circuit
Mounting Holes
Oled

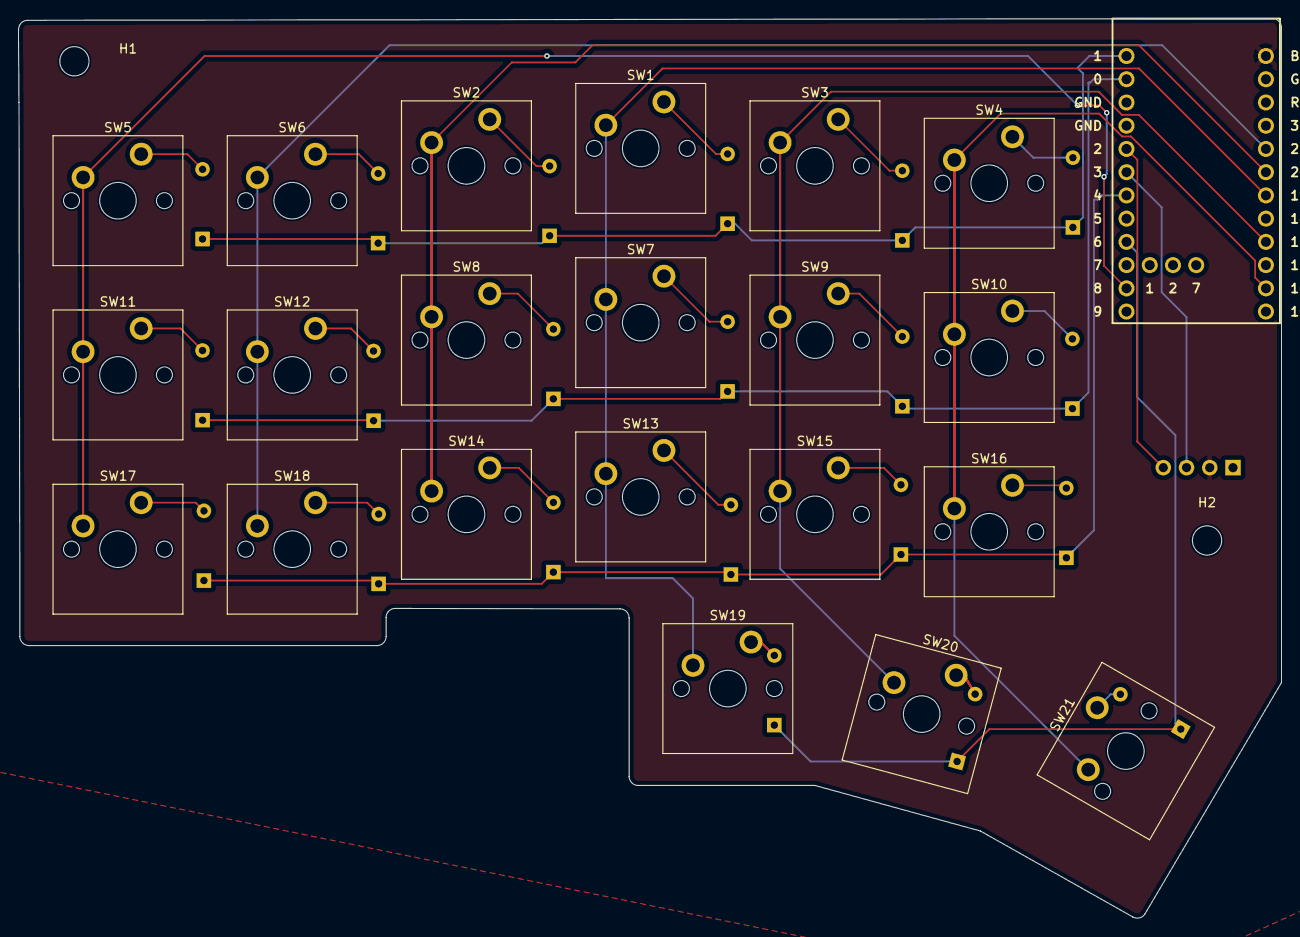
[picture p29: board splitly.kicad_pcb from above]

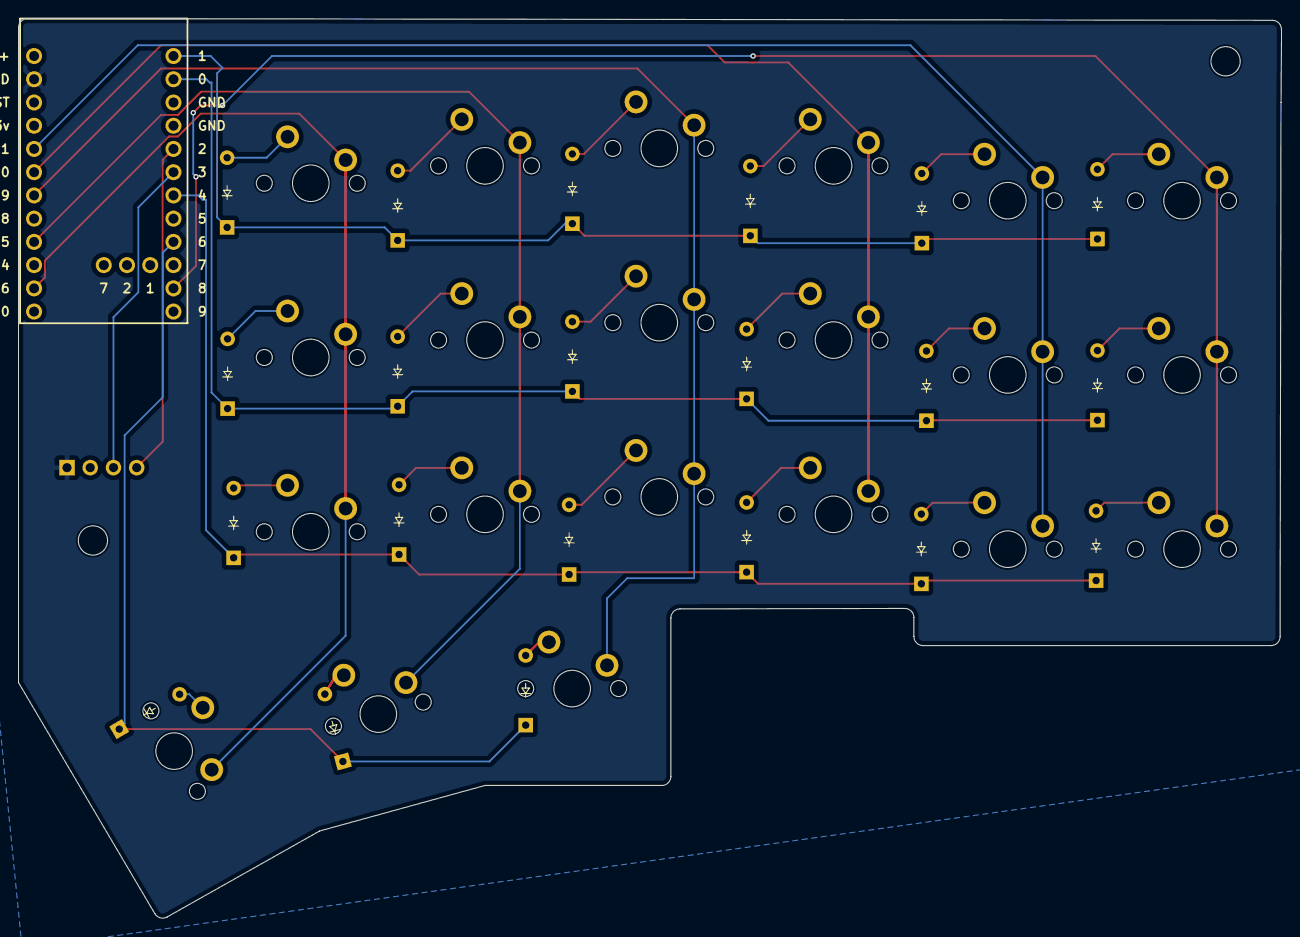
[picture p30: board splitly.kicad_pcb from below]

Board: 2 copper layers, 138.1 x 98.3 mm, 46 parts (21 on the bottom side), 35 nets.

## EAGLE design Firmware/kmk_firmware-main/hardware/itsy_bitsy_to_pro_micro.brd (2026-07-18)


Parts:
FRAME2: FRAME-LETTER; CREATIVE_COMMONS
JP1: HEADER-1X570MIL; 1X05_ROUND_70
JP2, JP4: HEADER-1X14; 1X14_ROUND70
JP3, JP5: M12PTH; 1X12

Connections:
!RESET: JP3.3, JP4.14
+3V3: JP4.13
A0: JP3.5, JP4.10
A1: JP3.6, JP4.9
A2: JP3.7, JP4.8
A3: JP3.8, JP4.7
A4: JP3.9, JP4.6
A5: JP3.10, JP4.5
AREF: JP4.12
D2: JP4.1
D3: JP1.4
D4: JP1.5
D5_5V: JP2.10
D7: JP2.9, JP5.1
D9: JP2.8, JP5.2
D10: JP2.7, JP5.3
D11: JP2.6, JP5.4
D12: JP2.5, JP5.5
D13: JP2.4, JP5.6
EN: JP1.1
GND: JP2.2, JP3.2, JP5.9, JP5.10
MISO: JP4.2
MOSI: JP3.12, JP4.3
RAW_PM: JP3.1
RX_D0: JP2.14, JP5.11
SCK: JP3.11, JP4.4
SCL: JP2.11, JP5.7
SDA: JP2.12, JP5.8
SWCLK: JP1.3
SWDIO: JP1.2
TX_D1: JP2.13, JP5.12
VBAT: JP2.1
VBUS: JP2.3, JP3.4
VHI: JP4.11

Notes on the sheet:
TX0/PD3->TX RX1/PD2->RX GND->GND GND->GND 2/PD1->SDA 3/PD0->SCL 4/PD4->13 5/PC6->12 6/PD7->11 7/PE6->10 8/PB4->9 9/PB5->7
OLD
Raw-> GND->GND RST->RST VCC->USB A3/PF4->A0 A2/PF5->A1 A1/PF6->A2 A0/PF7->A3 15/PB1->A4 14/PB3->A5 16/PB2->SCK 10/PB6->MOSI
Bryan Siepert



Board: 2 copper layers, 35.8 x 20.7 mm, 6 parts (2 on the bottom side), 21 nets.

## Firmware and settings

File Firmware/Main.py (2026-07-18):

print("starting")

import board 
import busio
from kmk.kmk_keyboard import KMKKeynboard
from kmk.keys import KC
from kmk.scanners import DioderOrientation
from kmk.modules.layers import Layers
from kmk.modules.modtap import ModTap
from kmk.extensions.display import Display, TextEntry, ImageEntry
from kmk.extensions.display.ssd1306 import SSD1306
from kmk.modules.split import Split , SplitSide
from kmk.hid import HIDModes


keyboard = KMKKeynboard()
keyboard.col_pins(board.GP8,board.GP21,board.GP20,board.GP19,board.GP15,board.GP14)
keyboard.row_pins(board.GP1,board.GP2,board.GP4,board.GP6)
keyboard.diode_orientation = DioderOrientation.COL2ROW
keyboard.modules.append(Layers())
keyboard.modules.append(ModTap())
_main, f_st,S_cd,l_st = 0,1,2,3

Clt_ESCE = KC.MT(KC.ESC.KC.LCTL)
ent_super = KC.MT(KC.ENTER, KC.LGUI)
tab_lower = KC.LT(f_st,KC.TAB)

i2c_bus  =  busio.I2C(board.GP,board.GP)
display_driver = SSD1306( i2c = i2c_bus, device_address = 0x3c),
display = Display(
    display = display_driver,
    entries = 
        [
        TextEntry(text='@Youssef', x = 128,y=0,x_anchor = 'R',y_anchor = 'T'),
        ImageEntry(image = "D:\Splitly\Splitly\Firmware\vert_cat.bmp",x=0,y=0),
        ],
        height = 64,
        of_time = 1200,
        brightness = 0.5,
        brightness_step = 0.2,
        dim_time  = 500,
        dim_target = 0.1,
)
keyboard.extensions.append(display)
split = Split (
    split_side = Split.LEFT,
    uart_flip = True,
)
keyboard.modules.append_split(split)
keyboard.keymap = [
    # _main
    [
        KC.TAB,KC.Q,KC.W,KC.E,KC.R,KC.T,
        KC.ALT,KC.A,KC.S,KC.D,KC.F,KC.G,
        KC.LSFT,KC.Z,KC.X,KC.C,KC.V,KC.B,
        KC.NO,KC.NO,KC.NO,Clt_ESCE,ent_super,tab_lower,
    ]
    ,
    # f_st
    [
        KC.TRNS,KC.EXLM,KC.AT,KC.HASH,KC.DLR,KC.PERC,
        KC.TRNS,KC.N1,KC.N2,KC.N3,KC.N4,KC.N5,
        KC.TRNS,KC.TRNS,KC.TILD,KC.TRNS,KC.TRNS,KC.LCBR,
        KC.TRNS,KC.TRNS,KC.TRNS,KC.TRNS,KC.TRNS,KC.TRNS,
    ]
    ,
    # S_cd
    [
        KC.TRNS,KC.DEL,KC.TRNS.KC.UNDS,KC.PLUS,KC.PGUP,
        KC.TRNS,KC.HOME,KC.END,KC.EQL,KC.TRNS,KC.PGDN,
        KC.TRNS,KC.TRNS,KC.TRNS,KC.LCTL(KC.C),KC.LCTL(KC.V),KC.TRNS,
        KC.TRNS,KC.TRNS,KC.TRNS,KC.TRNS,KC.TRNS,KC.TRNS,
    ]
    , # l_st
    [
       KC.TRNS,KC.F1,KC.F2,KC.F3,KC.F4,KC.F5,
       KC.TRNS,KC.F11,KC.F12,KC.TRNS,KC.TRNS,KC.TRNS,
       KC.TRNS,KC.TRNS,KC.TRNS,KC.TRNS,KC.TRNS,KC.TRNS,
       KC.TRNS,KC.TRNS,KC.TRNS,KC.TRNS,KC.TRNS,KC.TRNS,
       ]
]

if __name__ == '__main__' :
    keyboard.go()

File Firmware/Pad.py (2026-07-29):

print("Starting")

import board
import busio 

from kmk.kmk_Keyboard import KMKKeyboard
form kmk.keys import KC
from kmk.scanners import DiodeOrientation
from kmk.encoder import EncoderHandler
from kmk.extensions.rgb import RGB


keyboard = KMKKeyboard()
keyboard.col_pins = (board.GP13,board.GP14,board.GP22,board.GP22)
keyboard.row_pins = (board.GP0,board.GP3,board.GP6,board.GP8,board.GP10,board.GP11)
keyboard.diode_orientation = DiodeOrientation.COL2ROW

keyboard.keymap = [
    KC.NO,KC.NO,KC.NO,KC.NO,
    KC.P7,KC.P8,KC.P9,KC.PPLS,
    KC.P4,KC.P5,KC.P6,KC.NO,
    KC.P1,KC.P2,KC.P3,KC.PENT,
    KC.P0,KC.PDOT,KC.NO,KC.NO,

]
encoder_handler = EncoderHandler()
encoder_handler.pins = (
    (board.GP19,board.GP18,None),
    (board.GP17,board.GP16,None)
)

rgb_light = RGB (
    pixe_pin = board.GP20,
    num_pixels = 2,
    sat_default = 100,
    hue_default = 0 ,
    val_deafault = 100,
)
if __name__=='__main__':
    keyboard.go()

    

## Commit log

2026-07-16 left keyboard pcb& schematic & gerbers
    [bom.csv, designators.csv, positions.csv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]
2026-07-17 left_keyboard 3d models
    [Left_Assembly.f3z, Left_Assembly.step, Left_ENclosure.f3d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]
2026-07-17 right pcb
    [bom.csv, designators.csv, positions.csv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]
2026-07-18 Rigth Part assembly& all corne keyboard rendering
    [1.5u.step, Battery.f3d, Battery.step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]
2026-07-29 Numpad _Pad PCb & schematic
    [pad-B_Cu.gbr, pad-B_Mask.gbr, pad-B_Paste.gbr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]

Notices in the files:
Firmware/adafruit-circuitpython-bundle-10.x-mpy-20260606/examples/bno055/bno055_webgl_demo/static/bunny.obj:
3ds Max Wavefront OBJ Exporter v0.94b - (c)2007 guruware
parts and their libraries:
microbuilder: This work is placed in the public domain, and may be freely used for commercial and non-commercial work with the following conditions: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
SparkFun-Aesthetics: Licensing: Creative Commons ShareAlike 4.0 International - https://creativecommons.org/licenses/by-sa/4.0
